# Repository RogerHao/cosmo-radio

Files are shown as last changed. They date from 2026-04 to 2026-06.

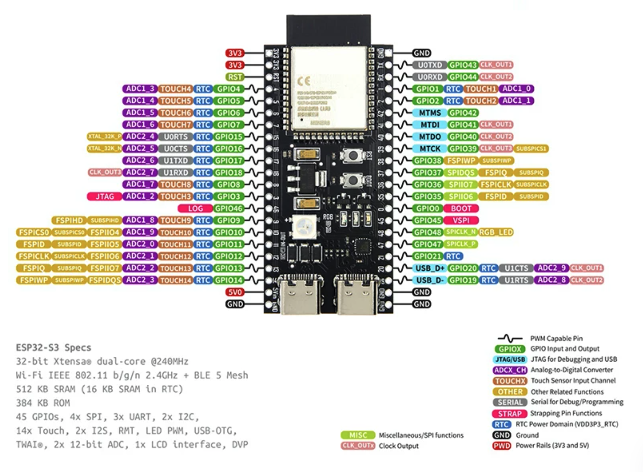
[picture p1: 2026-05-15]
docs/assets/ESP32-S3-DevKitC-N16R8.png

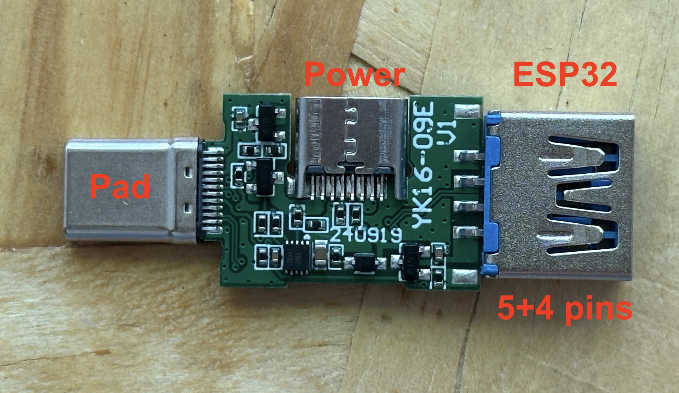
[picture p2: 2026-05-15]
docs/assets/otg-adapter-yk16-09e-photo.jpg

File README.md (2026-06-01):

# CosmoRadio

可穿梭于平行宇宙的 Radio 接收器

## 项目简介

桌面交互设备，安卓平板 + 3D 打印外壳 + ESP32 USB HID 控制器。造型参考 iMac G3 斜面站立式设计，用户通过旋钮调频、NFC 刷卡切换内容，仿佛在平行宇宙间搜索信号。

**当前版本：V4**（2026.04 — 2026.05）— 技术方案验证 + 单套原型制作

> 2026-04-29 与噗噗噗公司确认重启协议：第四期缩小为技术方案验证和单套原型制作，合同价 ¥5,000，目标 2026-05-20 左右交付。原 4 套整机 + 8 套电子套件交付范围已取消。

## 产品形态

- **外观风格**: iMac G3 斜面站立式，模块化三件式（主体 + 顶部 + 背板）
- **显示设计**: 三圆形遮罩（矩形屏幕通过开孔分割为三个圆形显示区）
- **输入方式**: 2 × EC11 旋钮 + Kailh 机械轴按钮 (6.25U 卫星轴) + NFC 刷卡
- **状态指示**: WS2812 RGB LED

## 硬件组成（V4）

| 组件 | 规格 | 用途 |
|---|---|---|
| 安卓平板 | 客户自购 (Samsung Galaxy Tab A9 8.7") | 主机，运行 Web 应用 |
| ESP32-S3 DevKitC N16R8 | 36+ GPIO / USB OTG / 16MB Flash / 8MB PSRAM | HID 控制器 |
| 定制 PCB 载板 | **100×100mm 双面** (JLCPCB 免费打样)，**两条 1×22 单排母** + 5 路 XH2.54 + 4× 10kΩ/10nF 去抖 | 消灭飞线，XH2.54 即插即用 |
| EC11 旋钮 × 2 | 15mm 半轴柄旋转编码器 | 频率调节 / 模式切换 |
| Kailh BOX 轴 + 6.25U 卫星轴 | 机械键盘蝴蝶结构，3.6mm 行程 | Action Button |
| RC522 mini NFC 模块 × 1 | 13.56MHz SPI，读 NTAG215 NDEF | NFC 刷卡交互（最终 1 个，2026-05-06 确认） |
| **OTG dongle (YK16-09E V1) 内置子板** | 拆 USB-A 母座，4 飞线接 J5 → DevKitC 排针 GPIO19/20 + 5V/GND | 平板 Data Host + Power Sink 同时工作 |
| 板载 RGB LED | DevKitC GPIO48 WS2812B | 状态指示（不外接 LED）|

## 连接方案

| 方案 | 固件位置 | 状态 |
|---|---|---|
| USB HID | 项目根目录 | **当前使用** — TinyUSB，即插即用 |
| BLE HID | (已删除，见 git 历史) | V1-V2 遗留，已停用 |

## 交互设计

输入设备通过 ESP32 USB HID 协议作为标准键盘连接到安卓平板，事件以模拟按键传递：

| 输入 | 映射 | 功能 |
|---|---|---|
| 顶部 Action 按钮 | Enter 键 | 确认选择 |
| EC11 左 旋转 | 上/下方向键 | 调节频率 |
| EC11 左 按下 | F1（占位，平板可重映射） | 扩展功能位 |
| EC11 右 旋转 | 左/右方向键 | 切换模式 |
| EC11 右 按下 | F2（占位，平板可重映射） | 扩展功能位 |
| NFC 卡（写了 NDEF Text） | `<payload>\n` | **主路径**：固件读卡上写入的字符串，原样键入 + Enter（无前缀） |
| NFC 卡（空白 / 非 NDEF） | `NFC:<UID>\n` | 兜底：识别失败时键入 UID 方便诊断 |

### NFC 协议设计

为了让产品身份与 NFC 卡 UID 解耦（UID 不可控且需要逐张录入），固件读取卡上的 NDEF Text Record 内容作为产品 ID。流程：

1. 出厂前用任一手机 NFC 工具 app 把每张卡写入特定字符串（如 `R01`、`track-42`）
2. 用户放卡 → 固件读 NDEF → HID 键入 `R01\n`
3. 平板侧 Android 应用结合页面状态/输入长度判断当前是 NFC payload 还是普通 HID 键入；`NFC:` 前缀仅出现在 UID 兜底路径，方便区分

### LED 状态指示（DevKitC 板载 GPIO48 RGB LED）

| 事件 | LED 颜色 |
|---|---|
| 按钮按下 | 红色 |
| 按钮释放 | 熄灭 |
| NFC 识别中（键入期间） | 蓝色 |
| 启动完成 | 绿色闪烁 |

## 项目结构

```
cosmo-radio/                            # 项目根 = ESP-IDF USB HID 固件
├── main/
│   ├── tusb_hid_example_main.c         # 入口：USB HID + ASCII→HID 编码
│   ├── input_handler.c/h               # GPIO 中断 + 物理电平复核输入（按钮 + 双 EC11）
│   ├── nfc_handler.c/h                 # RC522 SPI 扫描 + NDEF Text 解析
│   └── led_indicator.c/h               # 板载 WS2812 RGB（GPIO48）
├── sdkconfig.defaults
├── CMakeLists.txt
├── pcb/                                # 嘉立创EDA r1.0 验证版工程 + 制造文件
├── models/                             # 3D 模型（v4 = 最终交付集）
├── docs/
│   ├── assets/                         # 元器件引脚图、原型照片
│   ├── firmware/                       # 固件实现文档
│   ├── hardware/                       # 硬件模块设计方案（NFC、USB...）
│   ├── legacy/                         # 弃用内容
│   └── project/ → codex                # BOM、PCB Spec、项目主文档
└── test/
    └── hid-test.html
```

## 相关项目

- [cosmo-pager-web-nextjs-vercel](https://github.com/RogerHao/cosmo-pager-web-nextjs-vercel) — Web 应用前端（客户软件团队开发）

## 版本历史

| 版本 | 时间 | 主控 | 连接 | 主要变化 |
|---|---|---|---|---|
| V1 | 2025 Q3-Q4 | Adafruit HUZZAH32 | — | 硬件预研 |
| V2 | 2025.12-2026.01 | XIAO ESP32S3 | BLE HID | 首批组装，硅谷交付 |
| V3 | 2026.01-2026.02 | ESP32-S3 SuperMini | USB HID | BLE→USB 切换，12 套交付 |
| **V4** | **2026.04-2026.05** | **ESP32-S3 DevKitC N16R8** | **USB HID** | **模块化 PCB + NFC + 机械按钮，单套原型验证** |

## V4 进度

**2026-06-01 第四期结项 ✅**——技术验证 2026-05-22 完成，2026-05-31 客户收到成品交付，2026-06-01 开票收款 ¥5,000（累计 ¥31,000 全部结清）。

**2026-05-22 V4 技术验证交付完成 ✅**——PCB r1.0 实焊 + 双板并排功能验证通过，单套原型装配完成。详见 [V4 资料包](project/v4/shared/先读说明.md)。

已交付：
- [x] 2026-04-29 与噗噗噗公司重启 V4：技术方案验证 + 单套原型，合同价 ¥5,000
- [x] USB-C 充电方案：被动 SS34 注入实测失败 → 内置一分二 OTG 线材子板（YK16-09E V1）验证通过
- [x] NFC 数量确认：1 个 RC522 mini（2026-05-06）
- [x] 万能板飞线原型焊接 + GPIO 验证（2026-05-06，[图片](docs/assets/v4-handmade-prototype-2026-05-06.jpg)）
- [x] 固件 V4 GPIO 迁移（SuperMini → DevKitC N16R8）+ HID 多键并发
- [x] NFC 驱动开发（RC522 SPI + NDEF Text Record 解析）
- [x] 旋钮 + NFC HID 协议定稿（NDEF payload 原样键入，无前缀 + `NFC:<UID>` 兜底）
- [x] 端到端验证：iPhone 写卡 → ESP32 读 NDEF → HID 键入（2026-05-15 实卡验证）
- [x] **PCB r1.0 载板**：嘉立创EDA手绘 → 打样 → 实焊 → 功能验证（源文件 `pcb/cosmoradio-v4-jlceda/`）
- [x] 单套整机原型装配（[Fusion 装配 `cosmo-radio-v4-prototype`，模型 `models/v4/`]）
- [x] Action Button 最终手感、整机热稳定 + 2h 充电链路、NFC 穿透壁厚读距回归（2026-05-24 结项确认）
- [x] 固件安全回归：按钮释放物理电平复核、HID key-up 重试、NFC 启动后台重试（2026-05-28 PCB 实机烧录验证）

结项归档待办：
- [ ] PCB 制造文件从嘉立创EDA导出归档（清单见 [pcb/README.md](pcb/README.md)）
- [ ] r1.1 优化（J4 改对称去 walkaround、NFC 5MHz）— 见验证报告 §6

## 构建与烧录

```bash
get_idf                                    # 激活 ESP-IDF 环境
idf.py set-target esp32s3                  # 设置目标芯片（首次）
idf.py build                               # 构建
idf.py -p /dev/cu.usbmodem* flash monitor  # 烧录并监控
```

> ⚠️ 烧录必须走 DevKitC 的 **UART USB-C** 口（本板 UART 桥是 WCH CH343），别插 native/OTG 口——两个口在 macOS 下都枚举成 `usbmodem`，靠 USB VID 区分（`0x1A86`=UART 桥可烧 / `0x303A`=OTG 口烧不了）。详见 [CLAUDE.md "烧录端口"](CLAUDE.md)。

## GPIO 引脚分配

完整 GPIO → net → 连接器 映射、PCB 物理位置、PCB r1.0 EC11-R 接线 walkaround 全部见 [CLAUDE.md "GPIO Pin Assignments"](CLAUDE.md#gpio-pin-assignments-v4-pcb-r10--esp32-s3-devkitc-n16r8)。固件里 `main/input_handler.c` 和 `main/nfc_handler.c` 的 `#define` 是各自的 GPIO 角色权威源。

> 简易记忆：左旋钮 → J3，右旋钮 → J4 (引脚顺序跟 J3 镜像)，BTN → J1，NFC → J2，USB → J5。V3 引脚分配（SuperMini）见 git 历史。

## 文档索引

**交付（客户）**
- [V4 资料包先读](project/v4/shared/先读说明.md) ⭐ 交付核心
- [产品功能与当前边界](project/v4/shared/产品功能与当前边界.md)
- [平板对接协议](project/v4/shared/平板对接协议.md)
- [硬件参考资料](project/v4/shared/硬件参考资料.md)
- [复现与维护指南](project/v4/shared/复现与维护指南.md)
- [物料清单与采购参考](project/v4/shared/物料清单与采购参考.md)

**硬件方案**
- [USB 接口方案](docs/hardware/usb.md)
- [NFC 模块方案](docs/hardware/nfc.md)
- [OTG 一分二适配器（内置子板）](docs/hardware/otg-adapter.md)

**内部**
- [V4 内部成本备忘录](project/v4/internal/CosmoRadio-V4-内部成本备忘录.md) — 内部，不交付
- [V4 项目内部主文档](project/v4/internal/cosmoradio-yangweile-customized-hardware.md) — 内部，不交付
- [V4 待办事项](TODO.md)

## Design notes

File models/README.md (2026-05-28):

# CosmoRadio 3D 模型

外壳与结构件的 3D 打印模型索引。`v4/` 是 V4 技术验证交付模型集，对应单套原型（iMac G3 斜面站立式，三圆形 IOI 遮罩 + 顶部 Action Button + NFC）。Fusion 360 云端装配工程名：`cosmo-radio-v4-prototype`。

> 模型二进制文件（STL / 3MF / STEP）被 `.gitignore` 排除，不进 git。交接/交付时，实际模型文件走飞书或独立压缩包；不能靠 clone 仓库获得。

详细打印文件和截图见：[V4 交付包 / 3D打印文件](../project/v4/shared/3D打印文件/)。

## v4/ — V4 模型集

### STL 零件

| 文件 | 零件 | 说明 |
|---|---|---|
| `外壳主体.stl` | 外壳主体 | 三圆遮罩开孔主体 |
| `外壳背板.stl` | 外壳背板 | 主背板 |
| `充电背板.stl` | 充电口背件 | OTG / 充电线材出入口结构 |
| `按钮安装外壳.stl` | Action Button 安装座 | Kailh BOX 轴 + 6.25U 卫星轴安装结构 |
| `圆润按钮.stl` | 圆润按钮键帽 | 默认按钮形态 |
| `标准按钮.stl` | 标准按钮键帽 | 备选按钮形态 |
| `NFC安装外壳.stl` | NFC 安装外壳 | RC522 mini 模块安装壳 |
| `NFC固定支架.stl` | NFC 固定支架 | NFC 模块压紧 / 固定件 |
| `平板固定支架.stl` | 平板固定支架 | 已进入整套打印工程 Plate 4 |
| `底部圆脚.stl` | 底部圆脚 | 单套 4 个 |
| `旋钮.stl` | EC11 旋钮帽 | 单套 2 个 |

### 3MF 工程

| 文件 | 说明 |
|---|---|
| `CosmoRadio-V4-整套打印.3mf` | 正式整套打印工程，含 4 个 plate：外壳主体 / 配件 / 外壳背板 / 充电背板及平板固定支架 |
| `NFC固定支架.3mf` | 历史整套工程副本，交付时以 `CosmoRadio-V4-整套打印.3mf` 为准 |
| `外壳主体.3mf` | 外壳主体单件工程 |
| `外壳背板.3mf` | 外壳背板单件工程 |
| `充电模块.3mf` | 充电口背件单件工程 |
| `按钮安装外壳.3mf` | Action Button 安装座单件工程 |
| `标准按钮.3mf` | 标准按钮键帽单件工程（备选按钮） |
| `NFC安装外壳.3mf` | NFC 安装外壳单件工程 |
| `NFC测试标签.3mf` | NFC 标签 / 测试件，不属于整机必需外壳件 |

### 打印信息

| 文件 | 说明 |
|---|---|
| `打印信息/整套打印-plate截图.png` | 当前整套工程 plate 排布截图 |
| `打印信息/打印截图.png` | 旧版 plate 排布截图 |
| `打印信息/打印消耗.png` | Bambu Studio 预估耗材和时间截图 |

当前整套工程预估：4 个 plate，PLA 397.70g，总打印时间 12h57m。完整参数见 V4 3D 打印说明。

## 历史版本

| 目录 | 版本 | 主控 | 形态 |
|---|---|---|---|
| `v1/` | V1（2025 Q3-Q4） | Adafruit HUZZAH32 | 硬件预研，多版前后壳迭代 |
| `v2/` | V2（2025.12-2026.01） | XIAO ESP32S3 | BLE HID，硅谷首批组装 |
| `CosmoRadio-V3-模型及拓竹P2S打印工程切片文件/` | V3（2026.01-2026.02） | ESP32-S3 SuperMini | USB HID，12 套交付（含 STEP 源 + P2S 切片） |

V3 目录含完整 `.step` 参数化源文件；v1/v2/v4 主要为 STL/3MF。

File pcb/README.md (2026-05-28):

# CosmoRadio V4 PCB

> **状态（2026-05-22）**：**r1.0 已打样 + 实焊 + 双板并排固件验证通过**。这是 V4 技术验证交付的 PCB 终版。
>
> **设计源文件唯一权威**：[`cosmoradio-v4-jlceda/`](cosmoradio-v4-jlceda/)（嘉立创EDA专业版手绘）。
> 仓库历史里出现过的 KiCad `cosmoradio-v4-carrier/`（Plan v2，circuit-synth + pcbnew 自动布线备选）**从未打样、未使用，已删除**——如需追溯见 git 历史。

CosmoRadio V4 的 PCB 是一块 **ESP32-S3 DevKitC N16R8 载板（carrier board）**，用于技术方案验证和单套原型制作。目标不是量产最优，而是：可快速打样、可手工装配、可稳定验证 USB HID + 外部充电 + 旋钮 + 按钮 + NFC、出问题易测量返修。

---

## 设计源文件与制造产物

| 文件 | 内容 | 状态 |
|---|---|---|
| [`cosmoradio-v4-jlceda/cosmoradio-v4-r1.0.epro2`](cosmoradio-v4-jlceda/) | 嘉立创EDA专业版可移植工程（原理图 + PCB） | ✅ 验证版唯一真源 |
| [`cosmoradio-v4-jlceda/cosmoradio-v4-r1.0-schematic.png`](cosmoradio-v4-jlceda/) | 原理图渲染（从工程导出） | ✅ |
| `cosmoradio-v4-jlceda/manufacturing/` | Gerber / 钻孔 / 坐标 / BOM / 原理图 PDF / STEP / DXF | ✅ 已导出归档 |

### 从嘉立创EDA专业版导出制造文件（清单）

> 制造文件无法从 `.epro2` 的 JSON 直接生成，必须在嘉立创EDA专业版 GUI 里导出（参 [官方文档](https://prodocs.lceda.cn/cn/pcb/export-pcb-fabrication-file-gerber/)）。
> 当前 r1.0 导出文件已归档到 `manufacturing/`。如需重新导出，用 v3.2.135+ 打开 `cosmoradio-v4-r1.0.epro2` 后，逐项导出到 `manufacturing/`：

| # | 产物 | 菜单路径 | 备注 |
|---|---|---|---|
| 1 | **Gerber + 钻孔** | `文件 → 导出 → PCB制板文件（Gerber）` | 输出一个 zip（.GTL/.GBL/.DRL…），即 JLCPCB 上板包 |
| 2 | **坐标文件**（贴片） | `导出 → 坐标文件` | SMT 用；本板被动件少，仅 8× 0805 |
| 3 | **BOM** | `导出 → BOM` | 物料清单 |
| 4 | **原理图 PDF** | `原理图编辑器 → 导出 → PDF/图片` | |
| 5 | **PCB PDF / 图片** | `PCB编辑器 → 导出 → PDF/图片` | 含丝印/阻焊层，便于核对 |
| 6 | **3D STEP** | `PCB编辑器 → 导出 → 3D文件` | 给结构设计对位用 |
| 7 | **板框 DXF** | `文件 → 导出 → DXF` | 给结构设计对位用 |

> 上板前用嘉立创 DFM 工具或 Gerber 查看器复核一遍再下单。导出完成后把文件放进 `manufacturing/`，我来核对归档。

---

## 当前范围

| 项目 | 结论 |
|---|---|
| 合作状态 | 2026-04-29 与 Arthur 重启 V4 |
| 当前交付 | 技术方案验证 + 单套原型制作 |
| 合同价 | ¥5,000 |
| 核心风险 | PCB 设计与验证（已通过） |
| 非当前目标 | 原 4 套整机 + 8 套电子件批量交付 |

## 验证里程碑

**2026-05-07 整体方案验证完成 ✅**——电气、固件、NFC 协议在万能板飞线版上端到端跑通，所有方案级未知收敛。

| 项目 | 状态 |
|---|---|
| NFC 数量 | ✅ 1 个 RC522 mini |
| 一分二 OTG + 充电线材 | ✅ 多型号实测，选定 YK16-09E V1 作内置子板基准 |
| 手工万能板原型 | ✅ 已焊（[图片](../docs/assets/v4-handmade-prototype-2026-05-06.jpg)） |
| GPIO 分配 | ✅ V4 终版定稿，权威表见 [CLAUDE.md](../CLAUDE.md) |
| RC522 NFC 驱动 | ✅ 1MHz SPI + NDEF Text Record 解析 |
| HID 协议 | ✅ NDEF payload 主路径 + `NFC:<UID>` 兜底 |
| 端到端验证 | ✅ iPhone 写卡 → ESP32 读 NDEF → HID 键入 |

**2026-05-22 PCB r1.0 实焊验证完成 ✅**

- ✅ 嘉立创EDA手绘原理图 → 打样 → 焊接 → DevKitC 插入 → JST 端子线压接
- ✅ 双 EC11 + Action Button + NFC + USB HID 全链路验证通过（两台板子并排测）
- ⚠ **已知 r1.0 issue**：J4 (EC11-R) 引脚顺序画成跟 J3 镜像，物理 EC11 端子线序错位。**固件已 walkaround**（`main/input_handler.c` 重指派 `GPIO_ENC2_A/B/SW` + swap A↔B，见 [CLAUDE.md "PCB r1.0 EC11-R 接线 walkaround"](../CLAUDE.md)），硬件无需返工。
- ⚠ 原理图里 H-L pin1 / H-R pin1·pin2 的 GND/+5V 标签标错；r1.0 因走线没真连而幸免，r1.1 应改正。
- ⏳ 待新 Tab A9 到货后补整机长时间热稳定 + 2h 充电链路回归（当前在安卓手机上验证）。

## 板子定位

ESP32-S3 DevKitC 通过 2.54mm 排母插在载板上（不焊死，易更换），载板只负责固定主控与外设线束、消灭 V3 的飞线、把旋钮/按钮/NFC/USB 标准化、提供必要的上拉/RC 去抖。

```mermaid
flowchart LR
    tablet[Android 平板 Tab A9] <-- USB HID --> pcb[CosmoRadio V4 载板 r1.0]
    charger[USB-C 充电器] --> dongle[内置 OTG dongle 子板]
    dongle --> pcb
    pcb --> devkit[ESP32-S3 DevKitC N16R8]
    pcb --> enc1[EC11 左旋钮 J3]
    pcb --> enc2[EC11 右旋钮 J4]
    pcb --> btn[Action Button J1]
    pcb --> nfc[RC522 NFC J2]
```

## 接口定义（r1.0）

权威 GPIO → net 映射见 [CLAUDE.md "GPIO Pin Assignments"](../CLAUDE.md)。下表为 PCB 视角的连接器物理接线：

| Ref | 接口 | 类型 | 连接对象 | 信号（按 pin 顺序）|
|-----|---|---|---|---|
| H-L | DevKitC 左列 socket | 1×22P 排母 2.54mm | DevKitC 左侧排针 | 含 GPIO19/20 + EC11-L + BTN |
| H-R | DevKitC 右列 socket | 1×22P 排母 2.54mm | DevKitC 右侧排针 | 含 EC11-R + NFC SPI |
| J1 | BTN | XH2.54 2P | Kailh BOX 按钮 | pin1=SIG, pin2=GND |
| J2 | NFC | XH2.54 8P | RC522 mini | CS, SCK, MOSI, MISO, IRQ, GND, RST, VCC |
| J3 | EC11-L（用户左旋钮） | XH2.54 5P | 左旋钮 | pin1-5 = A, GND, B, GND, SW |
| J4 | EC11-R（用户右旋钮） | XH2.54 5P | 右旋钮 | pin1-5 = SW, GND, B, GND, A ⚠ 跟 J3 镜像，r1.1 改对称 |
| J5 | OTG USB 数据 | XH2.54 4P | OTG dongle 拆 USB-A 后 4 飞线 | pin1-4 = VBUS, D-, D+, GND |

> H-L 中心距 H-R = **22.86mm**（= 9 × 2.54mm pitch），breadboard 兼容，以飞线万能板实测为准。

## 原理图元件清单（r1.0，14 元件 + 4 螺柱位）

| Ref | 元件 | 封装 | 说明 |
|-----|---|---|---|
| H-L, H-R | 1×22P 排母座 (×2) | 2.54mm THT | DevKitC 插入 |
| J1 | XH2.54 2P 立式直针座 | THT | Action Button |
| J2 | XH2.54 8P 立式直针座 | THT | RC522 NFC |
| J3, J4 | XH2.54 5P 立式直针座 (×2) | THT | EC11 旋钮 |
| J5 | XH2.54 4P 立式直针座 | THT | OTG dongle USB 数据 |
| R1-R4 | 10kΩ 上拉（EC11 A/B） | 0805 | LCSC C17414 |
| C1-C4 | 10nF 对 GND（EC11 A/B） | 0805 X7R 50V | RC 去抖，τ=100µs |
| U1-U4 | M2.5 固定螺柱位 | 通孔 | 四角 |

**相对旧 spec 取消的元件**：USB-C 母座（充电改走 OTG dongle 内部）、USB-C CC 5.1k Rd ×4、SS34 防倒灌、外接 WS2812B + 330Ω（LED 改用 DevKitC GPIO48 板载 RGB）。

## PCB 物理约束

| 项目 | 值 |
|---|---|
| 尺寸 | **100mm × 100mm**（JLC 免费打样上限）|
| 层数 / 板厚 / 铜厚 | 2 层 / 1.6mm / 1oz |
| 表面 / 阻焊 / 丝印 | HASL 无铅 / 黑油 / 白字 |
| 安装孔 | 4 × M2.5（四角，孔径 2.7mm）|
| 制造 | JLCPCB 5 片打样 |
| 装配 | 不上 SMT；纯打板，8× 0805 + 6 个连接器手焊 ~15min |

连接器物理位置（用户俯视）：**顶部** J5；**左侧** J1（靠前）/ J3（中段）；**右侧** J4（中段）/ J2（底部）。顶丝印有 **"OTG USB-C: DO NOT PLUG"** 警示——GPIO19/20 同时连到 J5 和 DevKitC native USB-C 焊盘，运行时插板载 OTG USB-C 会跟 dongle 注入冲突；烧录走 DevKitC **UART** USB-C。

---

## 关键设计判断（决策记录）

### 混合焊接：低风险小器件贴片，高机械应力器件直插

| 类型 | 方案 | 理由 |
|---|---|---|
| 电阻 / 电容 | 0805 SMD | 适合加热台，布线短，易返修 |
| JST-XH 连接器 | 直插件 | 插拔受力大，原型更可靠 |
| DevKitC 排母 | 直插件 | 承重和插拔受力，不适合贴片 |

比全直插件整洁，比全贴片更适合单套原型。

### NFC 连接器按 8P 处理

以 RC522 mini 实物丝印为准：`CS, SCK, MOSI, MISO, IRQ, GND, RST, 3V3`（8P）。IRQ 第一版接出但固件未用，避免后续想做中断驱动时改板。

### EC11 A/B 加 RC 去抖

A/B 信号各加 10kΩ 上拉 + 10nF 对地（τ=100µs），既增强边沿陡度又抑制机械抖动——解决飞线版上"一格不准、内部上拉不够脆"的问题。SW 仅靠内部上拉。

### USB / 充电：选定"拆解成品 OTG dongle 内置"而非自研 PD 子板

核心约束：Tab A9 必须同时是 **Data Host**（host ESP32）+ **Power Sink**（被外部充电）——这不是 USB-C 默认角色组合，需要角色拆分。

- ✅ **成品一分二 OTG + 充电线材**已实测让 Tab A9/Android 同时 HID 输入 + 充电 → 证明设备支持该状态。V4 选定拆解 YK16-09E V1、取内部 PCB 内置（J5 4 飞线）。
- ❌ **被动 SS34 + 6P 转接板注入 VBUS**（2026-04-30 实测失败）：即使配 5.1k Rd，也只能让平板识别 OTG 设备，无法完成 Type-C/PD 角色协商进入充电态。已降级为失败路径记录，不再作为主线。
- ⏸ **自研 LDR6028/LDR6023C PD charge-through 子板**：技术可行但价值在形态可控而非降成本（不比 ¥20 级成品线材便宜，且有协议调试风险）。后续方案，不塞进第一版。
- ❌ **BLE HID + USB-C 只充电**：BLE HID 实测不稳定且违反"必须有线 HID"硬约束，排除。

> 深度调研见 [`research/Tab_A9_OTG_Charging_Feasibility_Report.md`](research/Tab_A9_OTG_Charging_Feasibility_Report.md)（2026-04-30 Manus 调研，针对半主动方案偏负面；后续实测一分二线材修正了"设备能力"判断，但确认被动复刻不够）。

---

## r1.1 路线（未启动，post-delivery）

r1.0 已满足 V4 技术验证交付。若后续迭代，r1.1 应：

1. 把 J4 (EC11-R) 引脚顺序改回跟 J3 对称的 `[A, GND, B, GND, SW]`，去掉固件 `input_handler.c` 里的 EC11-R walkaround。
2. 修正原理图里 H-L pin1 / H-R pin1·pin2 的 GND/+5V 误标。
3. 尝试把 NFC SPI 时钟从 1MHz 拉回 5MHz（铜箔走线 + 去耦后应可稳定，飞线版受 RF 噪声限制）。
4. 整机长时间热稳定 + 2h 充电链路回归（需新 Tab A9）。

## 目录

```
pcb/
├── README.md                          # 本文件
├── cosmoradio-v4-jlceda/              # ✅ r1.0 验证版唯一真源
│   ├── cosmoradio-v4-r1.0.epro2       #   嘉立创EDA可移植工程
│   ├── cosmoradio-v4-r1.0-schematic.png
│   └── manufacturing/                 #   Gerber/BOM/坐标/PDF/STEP/DXF
├── asset/                             # 飞线测试版照片 + DevKitC 引脚图
└── research/                          # Tab A9 OTG 充电可行性调研
```

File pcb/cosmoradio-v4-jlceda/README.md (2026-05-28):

# CosmoRadio V4 载板 — r1.0 验证版（嘉立创EDA专业版）

这是 **V4 实焊验证通过的 PCB 唯一权威设计源**。

| 文件 | 内容 |
|---|---|
| `cosmoradio-v4-r1.0.epro2` | 嘉立创EDA专业版可移植工程（zip：原理图 + PCB + 元件库）。用 v3.2.135+ 打开。 |
| `cosmoradio-v4-r1.0-schematic.png` | 原理图渲染（从工程导出，1920×1360） |
| `manufacturing/` | Gerber / 钻孔 / 坐标 / BOM / 原理图 PDF / STEP / DXF |

制造文件已归档到 `manufacturing/`。重新导出步骤（菜单路径、DFM 复核）见上层 [`../README.md`](../README.md) "从嘉立创EDA专业版导出制造文件"。

> r1.0 已知 issue（J4 镜像、H-L/H-R 标签误标）与 r1.1 路线见 `../README.md`。固件已 walkaround，硬件无需返工。

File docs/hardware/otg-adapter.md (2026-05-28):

# OTG 一分二适配器 — 集成分析

> 标记号：YK16-09E V1（板上丝印，日期码 240919）
> 用途：让 Tab A9 同时处于 **Data Host**（接收 ESP32 的 USB HID）+ **Power Sink**（被外部充电器充电）
> 当前状态：作为内置子板已采购、已实测 OTG + 充电同时工作；**仅剩 dongle USB-A ↔ ESP32 之间的一根 USB 3.0 线**外露在主板侧

参考图：[otg-adapter-yk16-09e-photo.jpg](../assets/otg-adapter-yk16-09e-photo.jpg)

## 1. 这块小板内部到底在做什么

从照片可以看到三个端口和板间一颗小型 IC：

| 端口 | 类型 | 角色 | 走向 |
|---|---|---|---|
| 左（"Pad"） | **Type-C 公头**（焊接式 plug，已带短缆） | DFP 视角的 Power Sink，但宣告自己是 USB Host (DFP/Host) 的 Data Role | 插入 Tab A9 |
| 中（"Power"） | **Type-C 母座** | UFP/Sink → 上行接外部充电器（Source） | 充电器 |
| 右（"ESP32"） | **USB 3.0 Type-A 母座**（9 pin） | 标准 USB Host 提供给下游设备 | 经一根 USB 3.0 线连到 ESP32-S3 DevKitC 自带 USB-C |

中间那颗带丝印的 IC 是关键，它干三件事：

1. **CC 线协商**：在朝向平板的 Type-C plug 上呈现 Rp（pull-up），并通过 PD BMC（或固定 CC pattern）告诉平板"我是 Host + Sink"。这一步用普通 5.1k 上拉/下拉电阻**做不到**——`pcb/README.md` 里 6P 转接板 + SS34 的失败就是这个原因。
2. **Power Role / Data Role 编排**：让平板内部把电源开关切到 Sink 路径（充电器电直接进电池），同时数据通路保持在 Host 模式（向下游提供 USB Host）。
3. **VBUS 路由 + 反灌保护**：把充电器的 5V 经高边 MOSFET 转接给平板 VBUS，同时阻止平板侧 VBUS 倒灌进充电器或下游设备。

这颗 IC 大概率是 LDR6028/LDR6023C 一族（5V OTG + 充电控制器）或 IP2721 类，**没有从板上拆下来在显微镜下看丝印之前不能 100% 确认**。

## 2. ESP32-S3 实际只用 9 pin 中的 4 pin

| 引脚 | 用途 | ESP32 是否用 |
|---|---|---|
| VBUS | 5V 电源 | ✅ 走 DevKitC 的 5V 输入 |
| GND  | 地 | ✅ |
| D+ / D- | USB 2.0 高速差分对（480 Mbps） | ✅ |
| StdA_SSRX± / StdA_SSTX± / GND_DRAIN | USB 3.0 SuperSpeed 通道（5 GT/s+） | ❌ 全部空跑 |

**结论**：USB-A 一侧 9 pin 里有 5 pin 完全是浪费。把这条 USB 3.0 线消灭只需要把 4 根线（VBUS、GND、D+、D-）从 dongle 直接接到主 PCB 即可。

## 3. 三种集成路径，按风险从低到高排

### 方案 1（推荐 V4 采用）：拆 USB-A 母座，4 根短线直连主 PCB

**做法**：
1. 把 dongle 上的 USB 3.0 Type-A 母座从板上拆下来（USB-A 受电力 + 信号都在板边焊盘，9 pin 加 2-4 个机械固定脚，热风枪 30s 可下件）。
2. 露出 4 个有用焊盘：VBUS、GND、D+、D-。
3. 焊 4 根 AWG28-AWG30 信号线到主 PCB 上一个新增的 4P XH2.54 连接器（或直接 4 个焊盘 + 应力释放）。
4. 主 PCB 这一侧用一根短跳线接到 ESP32-S3 DevKitC 的 USB-C 座（保持 DevKitC 不变）；或者后续 PCB rev 把 ESP32-S3 的 GPIO19/20/5V/GND 直接走到这个 4P 连接器，整条 USB-C 线也省掉。

**优点**：
- 不动 dongle 上的 PD/CC 控制 IC，电气行为 0 变化。
- 工艺非常确定：拆一个 USB-A 座 + 焊 4 根线，半小时收工。
- USB 2.0 HS 480 Mbps 在 <10 cm 短线上完全不需要阻抗匹配/length matching。
- 任何一头坏了都好换。

**缺点**：
- dongle 仍是一块独立小板，机械固定方案要做（双面胶 / 螺丝柱 / 卡扣）。
- BOM 里仍有"成品 dongle 整片"这一项，不是真正"自研一片主 PCB 含 OTG"。

**成本**：dongle ¥15-25 + 4 根线 ¥0 + 1 个 4P 连接器 ¥0.5。比当前少一根 USB 3.0 线（~¥10）。

**适合 V4** —— 04/29 重启的 V4 范围是"技术验证 + 单套原型"，2026-05-20 前要交付。这条路径**风险几乎为零**，今天就能动手。

### 方案 2：dongle USB-A 焊盘改 2.54 排针，主 PCB 出 4P 排母

**做法**：把 USB-A 拆掉后不焊飞线，而是焊一个 4P 2.54 直插排针；主 PCB 对应位置放排母。

**优点**：可拆卸，调试期间方便单独验证 dongle 或主 PCB。

**缺点**：增加了机械应力点，长期连接可靠性略差，不如直接焊死。

**适合**：调试阶段做，到最终组装再焊死，等于"1 + 2 混合"。

### 方案 3（推迟到 V5）：把 dongle 内部电路完整复刻到主 PCB

**做法**：
1. 拆 dongle，显微镜读丝印识别 CC 控制 IC（关键步骤——丝印不清就死路一条，需要好相机 + 侧光）。
2. 找到 datasheet 后，把 IC、外围被动件、ESD/TVS 阵列、VBUS 路径 MOSFET 全部画进 KiCad 原理图。
3. 主 PCB 上加 1 个 Type-C 充电母座 + 1 根 Type-C 公头 pigtail（去往平板）。
4. 重新过 JLCPCB（5 天打板 + 3 天到货），做 PD/CC 行为回归测试。

**优点**：彻底单板化、形态最干净、可量产。

**缺点 / 风险**：
- IC 识别失败 → 整条路径作废（实物焊在板上的 SOT-23-6/QFN 丝印往往只有 2-3 字符代号，要查代号表，不一定能查到）。
- 即使识别出 IC，PD/CC 行为复刻不一定 1:1 一致；Tab A9 这类设备对 CC 时序敏感，可能要协议分析仪才能调通。
- 时间预算 ≥ 一个 PCB rev cycle，约 10-15 天，**吃光 V4 剩余周期**。

**结论**：**不要塞进 V4。** 这是 V5（如果客户后续要小批量量产）才动的活。文档里把这条路径标为"未来工作"即可。

## 4. 给 V4 的具体决定

| 项 | 决定 |
|----|---|
| OTG dongle | **保留为内置子板**（YK16-09E V1） |
| dongle ↔ ESP32 之间的 USB 3.0 线 | **消灭**：拆 USB-A 母座 → 4 根飞线 → 主 PCB 4P XH2.54 连接器 |
| 主 PCB 上是否新增 PD/CC 控制 IC | **不新增** |
| 主 PCB 上是否新增 Type-C 母座（充电输入） | **不新增**（充电仍走 dongle 上自带的 Type-C 母座） |
| 朝向平板的 Type-C 公头线 | **保留 dongle 自带的**（它就是焊在 dongle 板上的 plug + 短缆） |
| 后续工作（V5+） | 显微镜读 IC 丝印 → 复刻入主 PCB |

## 5. 在动手之前要做的小件事（10 分钟）

1. **拍一张 dongle 中央 IC 的高分辨率照片**（手机 macro 或 USB 显微镜，侧光读丝印）。即使本期不复刻，IC 型号也是 V5 文档的金字塔基。把照片存成 `docs/assets/otg-adapter-yk16-09e-ic-marking.jpg`。
2. **量一下 dongle PCB 物理尺寸**（含 Type-C plug 短缆出板方向 + 长度 + 三个端口的开口位置），决定外壳里给它留哪一块平面 + 螺丝柱。
3. **确认 USB-A 母座下件后的 4 个焊盘极性**（VBUS、D-、D+、GND，从左到右是 USB-A 标准定义，但实物板可能镜像）。可以用万用表通断从 USB-A 金属壳和 4 个 pin 之间反查。

## 6. 主 PCB 改动清单

如果 V4 PCB 还没下单，加这几项；如果已经下单，飞线接也行：

- 新增 1 个 **J5（dongle USB 数据接入）** = 4P XH2.54 立式直插，位于 PCB 边缘靠近 ESP32-S3 DevKitC USB-C 那一侧。
- 信号顺序建议 `VBUS / D- / D+ / GND`（与 USB-A 物理顺序一致，方便排查）。
- VBUS 走线宽度 ≥ 0.6 mm（承载 ≤2 A 充电电流过路）。
- D+ / D- 走差分对，宽度 ~0.2 mm，间距 ~0.13 mm，长度匹配差 < 5 mm（USB 2.0 HS 容差很宽）。
- 在 J5 上的 D+ / D- 各预留一个不焊接的 ESD 二极管位（USBLC6-2 类或 0402 TVS），现版可以 0Ω 跳过。

## 7. 文档前后兼容

- `docs/hardware/usb.md` 中"方案 A / B / C"分析仍保留为历史参考，但其结论已被 dongle 实测 + 本文件覆盖。
- `pcb/README.md` 第 113-115 行的优先级表里，本方案对应 P1（"拆解一分二线材，取内部 PCB，短线/板内固定"），现在升级为 V4 主路径。
- BOM 与成本口径已归入 [物料清单与采购参考](../../project/v4/shared/物料清单与采购参考.md)：最终 OTG dongle 选型为 CKTUTU YK16-09E V1，¥10/个。

## 8. 一句话总结

**能集成，但分两步走。** V4 阶段把 dongle 当成"焊死的内置子板"，仅消灭 USB 3.0 长线（4 根飞线即可，零电气改动）；V5 阶段再考虑识别 dongle 上的 CC 控制 IC、整板复刻。这样 V4 deadline (2026-05-20) 守得住，长期可控性也保住了。

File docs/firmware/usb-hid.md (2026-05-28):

# USB HID 固件实现

> ⚠️ **2026-05-18 状态**：本文件原始内容（V2 XIAO ESP32S3 时代 GPIO 1/D0 描述）已过时，整理为下方简明版。
> 完整 V4 实现细节见 [`/CLAUDE.md`](../../CLAUDE.md) "HID Key Mappings" + "GPIO Pin Assignments"。

## 概述

基于 **TinyUSB** 的 USB HID 键盘实现，运行在 **ESP32-S3 DevKitC N16R8**。把物理输入（双 EC11 旋钮 + Kailh BOX 按钮 + RC522 NFC）转换为键盘事件。USB OTG 通过外置 dongle (YK16-09E V1) 实现"平板 USB Host + 充电"同时工作。

V1/V2 BLE HID 方案已删除（见 git 历史）；V3 SuperMini → V4 DevKitC N16R8 已完成迁移。

## 当前固件入口

| 文件 | 职责 |
|---|---|
| `main/tusb_hid_example_main.c` | TinyUSB 初始化 + ASCII→HID keycode 编码 + 多键并发报告管理（`s_pressed_keys[6]` + `s_hid_mutex`）|
| `main/input_handler.c/h` | GPIO 中断驱动状态机：Action Button + 双 EC11 (A/B/SW)，事件队列分发 |
| `main/nfc_handler.c/h` | RC522 SPI (1MHz, SPI2 via GPIO Matrix) + NDEF Text Record 解析 + 1.5s 同卡去重 |
| `main/led_indicator.c/h` | DevKitC GPIO48 板载 WS2812B RGB 状态指示 |

## HID 输入映射

权威表见 [/CLAUDE.md](../../CLAUDE.md) "HID Key Mappings"，简要：

| 输入 | HID 按键 |
|---|---|
| Action Button 按 | Enter |
| EC11-L 旋转 / 按 | ↑/↓ / F1 |
| EC11-R 旋转 / 按 | →/← / F2 |
| NFC 卡 (NDEF Text) | `<payload>\n` |
| NFC 卡 (UID 兜底) | `NFC:<UID_HEX>\n` |

> GPIO 号 / 连接器映射见 CLAUDE.md "GPIO Pin Assignments"，本文不重复。

## LED 行为

DevKitC GPIO48 板载 RGB（不外接 LED）：

| 事件 | 颜色 |
|---|---|
| 启动完成 | 绿色闪烁 |
| 按钮按下 | 红色 |
| NFC 识别中 | 蓝色 |

## 构建与烧录

```bash
get_idf                                    # 激活 ESP-IDF 环境
idf.py set-target esp32s3                  # 首次
idf.py build
idf.py -p /dev/cu.usbmodem* flash monitor  # 走 DevKitC UART USB-C 烧录，不走 OTG USB-C
```

> ⚠️ **烧录走 UART USB-C，不要走 OTG USB-C** — 板上 USB D+/D- 同时连到 J5 (dongle) 和 native USB-C 焊盘，外部插会冲突。详见 CLAUDE.md。

## 已知技术债

详见 [/CLAUDE.md](../../CLAUDE.md) "Known Limitations / Technical Debt"：

- NFC SPI 时钟暂用 1MHz（PCB 版可尝试拉回 5MHz）
- HID 多键并发已修复（2026-05-08 `s_pressed_keys[6]` + mutex）
- NFC 启动失败容错已实现（2026-05-10 warn 不 abort）
- sdkconfig 已升级 N16R8（2026-05-08 16MB QIO + 8MB Octal PSRAM）

## 硬件需求

详见 [/CLAUDE.md](../../CLAUDE.md) "Hardware Target (V4)" + [V4 硬件参考资料](../../project/v4/shared/硬件参考资料.md)。

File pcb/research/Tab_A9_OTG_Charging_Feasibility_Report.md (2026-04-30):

# CosmoRadio V4 专用 Tab A9 半主动 USB-C OTG + 充电方案可行性调研报告

## 1. 方案工作原理与机制分析

在 USB-C 和 Android 体系下，实现平板作为 USB Host（控制 ESP32-S3）同时接受外部充电，涉及到 USB 角色协商和电源路径管理的复杂机制。

### 1.1 标准行为与设备特定行为
*   **标准 USB-C DRP (Dual Role Port) 行为**：标准的 USB-C 接口通过 CC (Configuration Channel) 引脚进行角色协商。供电端（Source）在 CC 引脚上提供上拉电阻（Rp），受电端（Sink）提供下拉电阻（Rd，5.1kΩ）。双角色端口（DRP）在未连接时会交替呈现 Rp 和 Rd。当平板作为 USB Host 时，标准行为是它必须作为供电端（Source），向外输出 5V VBUS，此时其内部 CC 逻辑呈现 Rp [1]。
*   **SimulCharge / ACA (Accessory Charger Adapter) 机制**：在早期的 Micro-USB 时代，USB BC 1.2 规范定义了 ACA 机制，通过在 ID 引脚上接特定阻值的电阻（如 124kΩ 或 36.5kΩ），允许设备同时作为 USB Host 并接受充电 [2]。
*   **设备特定行为（Samsung 专有实现）**：在 USB-C 时代，虽然 USB PD 规范支持 Power Role Swap（电源角色交换）和 Data Role Swap（数据角色交换），但这需要完整的 PD 协议栈支持。对于低成本的半主动方案（不使用 PD 芯片），三星等厂商在底层固件中保留了类似 ACA 的模拟检测逻辑，或者允许在特定的 CC 电阻组合及 VBUS 强制注入时，触发“Host 模式下充电”的隐藏状态。这属于**高度设备特定**的行为，严重依赖于平板的内核驱动和充电 IC 固件 [3]。

## 2. 可行电路拓扑建议

针对“低复杂度、可集成到 PCB、不使用完整 PD 固件栈”的需求，建议采用以下半主动注入拓扑：

### 2.1 核心连接关系
1.  **外部充电器 VBUS 注入**：外部 5V 电源通过一个低压降的肖特基二极管（如 SS14 或 SS24）或者 P-MOSFET 理想二极管电路，注入到连接平板的 VBUS 线上。
2.  **平板端 CC 引脚配置**：
    *   在连接平板的 USB-C 插头的 CC 引脚上，需要配置特定的电阻网络来“欺骗”平板。
    *   **常规尝试**：接 5.1kΩ 下拉电阻（Rd）到地，使平板认为连接了充电器（进入 Sink 模式接受充电），同时强行在 D+/D- 上进行数据通信。
    *   **三星特定尝试（模拟 ACA）**：部分三星设备可能需要特定的 Rp 上拉（例如 56kΩ 到 5V）或者在 CC 线上施加特定电压，配合 D+/D- 上的设备连接，才能触发 SimulCharge 模式。
3.  **ESP32-S3 端**：ESP32 的 USB D+/D- 直接连接到平板的 D+/D-。ESP32 的供电可以直接取自外部注入的 5V VBUS。
4.  **防反灌保护**：**必须**在平板 VBUS 和外部充电器 VBUS 之间加入隔离。如果不加隔离，当外部电源断开时，平板会试图向外输出 5V（Host 模式默认行为），导致平板电池被外部电路迅速抽干 [4]。

### 2.2 推荐验证拓扑（第一版，已修正）
*   **最小拓扑**：`Tab_A9_VBUS` 直接作为 `SYS_5V` 给 ESP32 供电。`VBUS_IN -> SS34 -> Tab_A9_VBUS/SYS_5V`。无外部电源时，平板 Host 给 ESP32 供电；有外部电源时，外部 5V 通过 SS34 尝试注入同一节点。该拓扑只需要 1 颗 SS34。
*   **完整诊断拓扑**：验证板单独定义一个 `SYS_5V` 轨道给 ESP32 供电。`SYS_5V` 同时支持两种来源：
    *   无外部电源时：`Tab_A9_VBUS -> SS34/理想二极管 -> SYS_5V -> ESP32_5V`，由平板 Host 供电给 ESP32。
    *   有外部电源时：`VBUS_IN -> SS34/理想二极管 -> SYS_5V -> ESP32_5V`，由充电器供电给 ESP32。
*   **平板充电注入路径**：`VBUS_IN -> SS34/限流/eFuse -> Tab_A9_VBUS`，尝试让平板在 Host 模式下接受外部 VBUS。
*   **CC 引脚**：平板侧 CC1/CC2 尝试下拉 5.1kΩ 到 GND（基础 Sink 测试），或预留焊盘以便测试悬空/上拉。
*   **数据线**：ESP32 D+/D- 直连平板 D+/D-（注意 USB 2.0 走线尽量等长）。

## 3. 最小样板验证步骤

在进行 PCB 投板前，必须使用洞洞板或简单的转接板进行验证。

### 3.1 验证准备
*   准备一个 USB-C 母座（接外部电源）、一个 USB-C 公头（接 Tab A9）、一个 ESP32-S3 DevKit。
*   准备万用表、示波器、低压降肖特基二极管（如 SS24）、5.1kΩ 电阻。

### 3.2 测试步骤与测量项
1.  **基础充电测试**：只连接外部 5V 和 CC 下拉电阻到平板，万用表测量平板 VBUS 电压，确认平板是否显示充电。
2.  **数据连通测试**：在步骤 1 基础上，将 ESP32 的 D+/D- 接入，观察 ESP32 是否成功枚举为 HID 设备。
3.  **无外部电源 OTG 测试**：断开外部 5V，确认平板 `Tab_A9_VBUS` 能通过隔离路径拉起 `SYS_5V`，ESP32 能上电并枚举为 HID。
4.  **VBUS 冲突测试（关键）**：断开外部 5V，万用表测量外部充电输入端，确认平板输出的 VBUS 没有反灌到充电器输入。接入外部 5V 后，确认 `SYS_5V` 来源切换不导致 ESP32 掉电。
5.  **枚举中断测试**：在 ESP32 正常工作时，插拔外部 5V 电源，观察 ESP32 的 HID 连接是否会断开重连。

### 3.3 通过/失败标准
*   **通过**：Tab A9 显示充电（即使是慢充），且 ESP32 稳定枚举为 HID 并能发送数据；插拔充电器不导致 ESP32 掉线或仅有短暂可恢复的掉线。
*   **失败**：Tab A9 拒绝充电；或者充电时无法识别 ESP32；或者外部电源断开时，平板反向供电导致系统不稳定。

## 4. Tab A9 兼容性实测证据

针对 Samsung Galaxy Tab A9 (SM-X110) 的 SimulCharge 兼容性，调研结果**非常不乐观**。

1.  **LAVA 官方兼容性列表**：LAVA 是提供 SimulCharge 适配器的权威厂商。在其 Charge-Plus 兼容性列表中，**未列出**基础版 Tab A9 (SM-X110)。列表中仅提到了 Tab A7 Lite、Tab A8 等，且明确指出部分型号（如 Tab A7 Lite SM-T220）存在严重的电流限制 bug（电量不同时拉取的电流不同，甚至低至 0.5A），并建议**不要使用** [5]。
2.  **用户社区反馈**：在三星社区和 Reddit 上，多位用户反馈 Tab A9 和 A9+ 无法在使用普通 USB-C Hub 时同时进行 OTG 和充电。有用户明确表示“连接 USB-C 输入会点亮适配器，Android 显示正在充电，但无法与外设工作” [6]。
3.  **底层限制原因**：LAVA 的技术博客指出，如果移动设备没有实现完整的 USB-C PD 规范（Power Delivery），就无法与适配器协商电源契约，从而无法实现同时供电和数据传输 [7]。Tab A9 作为入门级平板，其 USB-C 接口仅支持 USB 2.0 且大概率**阉割了完整的 PD 角色交换功能**。

## 5. 可采购器件建议 (LCSC/立创商城)

为了控制 BOM 复杂度，建议采购以下基础器件进行验证：

*   **肖特基二极管（防反灌）**：
    *   **SS24** (Slkor / 长电)：2A，40V。价格极低（约 0.05 RMB），适合基础验证，但压降较大（约 0.5V）。
    *   **SS34**：3A 版本，余量更大。
*   **P-MOSFET（替代肖特基，降低压降）**：
    *   **AO3401A** (AOS / 长电)：-4.2A，-30V，SOT-23 封装。常用于简单的 VBUS 开关和防反接电路，导通电阻低 [8]。
*   **ESD 保护**：
    *   **USBLC6-2SC6** (ST / 各种国产替代)：专为 USB 2.0 D+/D- 设计的超低电容 ESD 阵列，SOT23-6 封装。

## 6. 风险清单

*   **平板拒绝充电 / 充电电流不足**：由于缺乏 PD 协商，平板可能只以默认的 500mA 甚至拒绝充电。
*   **枚举中断**：在插拔外部充电器时，VBUS 电压的波动可能导致 ESP32 重新启动或 USB 重新枚举，导致操作中断。
*   **反灌风险**：如果防反灌二极管失效或 P-MOSFET 栅极控制逻辑错误，外部 5V 和平板输出的 5V 发生冲突，可能烧毁平板接口。
*   **CC 配置错误**：错误的电阻值可能导致平板进入错误的模式（如纯供电模式），完全无法识别设备。

## 7. 最终结论与建议

**结论：针对 Tab A9 (SM-X110) 做纯硬件的“半主动”验证小板，风险极高，成功率较低，但考虑到项目成本限制，值得进行一次低成本的“死马当活马医”式验证。**

原因在于，大量证据表明 Tab A9 缺乏完整的 PD 协议支持，三星很可能在固件层面屏蔽了简单的电阻欺骗法。如果基础的下拉/上拉验证失败，则说明该平板**必须**依赖带 PD 芯片的复杂方案（如通过 FUSB302 等芯片进行角色交换协商），这将违背“低复杂度”的初衷。

### 第一版验证板原理图级连接清单：

1.  **VBUS_IN (外部 5V)** 连接到 **Diode_Anode** (肖特基阳极)。
2.  **Diode_Cathode** (肖特基阴极) 连接到 **Tab_A9_VBUS**。
3.  **最小拓扑**：**Tab_A9_VBUS** 直接连接到 **ESP32_5V_IN**，此时 **Tab_A9_VBUS** 同时也是 **SYS_5V**。
4.  **完整诊断拓扑**：**Tab_A9_VBUS** 通过第二路 SS34/理想二极管连接到 **SYS_5V**，保证无外部电源时平板能给 ESP32 供电。
5.  **完整诊断拓扑**：**VBUS_IN** 通过第三路 SS34/理想二极管连接到 **SYS_5V**，保证有外部电源时充电器给 ESP32 供电。
6.  **SYS_5V** 连接到 **ESP32_5V_IN**。
7.  **Tab_A9_CC1** 和 **Tab_A9_CC2** 各接一个 **5.1kΩ** 电阻到 **GND**（预留断开跳线）。
8.  **Tab_A9_D+** 直连 **ESP32_D+**。
9.  **Tab_A9_D-** 直连 **ESP32_D-**。
10.  所有设备的 **GND** 共地。

*建议先用切断 VBUS 线的 USB 数据线配合面包板进行测试，若步骤 3.2 中的测试均失败，则应果断放弃半主动方案，考虑更换平板型号或接受无法边充边用的现实。*

---
### 参考文献
[1] Texas Instruments. A Primer on USB Type-C and Power Delivery Applications.
[2] StackExchange. Can an Android tablet serve as USB Host and be charged simultaneously.
[3] XDA Forums. Guide..OTG USB HOST and CHARGING at same time for Galaxy tabs.
[4] Reddit. USB-C Prevent back powering in Host OTG-Mode.
[5] LAVA Accessory. Charge-Plus Compatibility List.
[6] Samsung Community. Galaxy Tab A9 USB and charging at the same time.
[7] LAVA Blog. Why Some USB-C Mobile Devices Can't Do Simultaneous Power and Data.
[8] LCSC. AO3401A Datasheet and Pricing.

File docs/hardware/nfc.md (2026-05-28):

# CosmoRadio V4 — NFC 模块方案

NFC 文档已迁移到 V4 交付包，后续只维护这些文件：

- `project/v4/shared/平板对接协议.md`
- `project/v4/shared/硬件参考资料.md`

迁移原因：

- 旧文档包含早期 `#<payload>` 协议、NTAG215 推荐和旧 GPIO 示例，已不符合最终交付状态。
- V4 交付包是客户验收文件夹，NFC 模块、标签、写卡规则、接线和验收说明应以交付包文档为准。

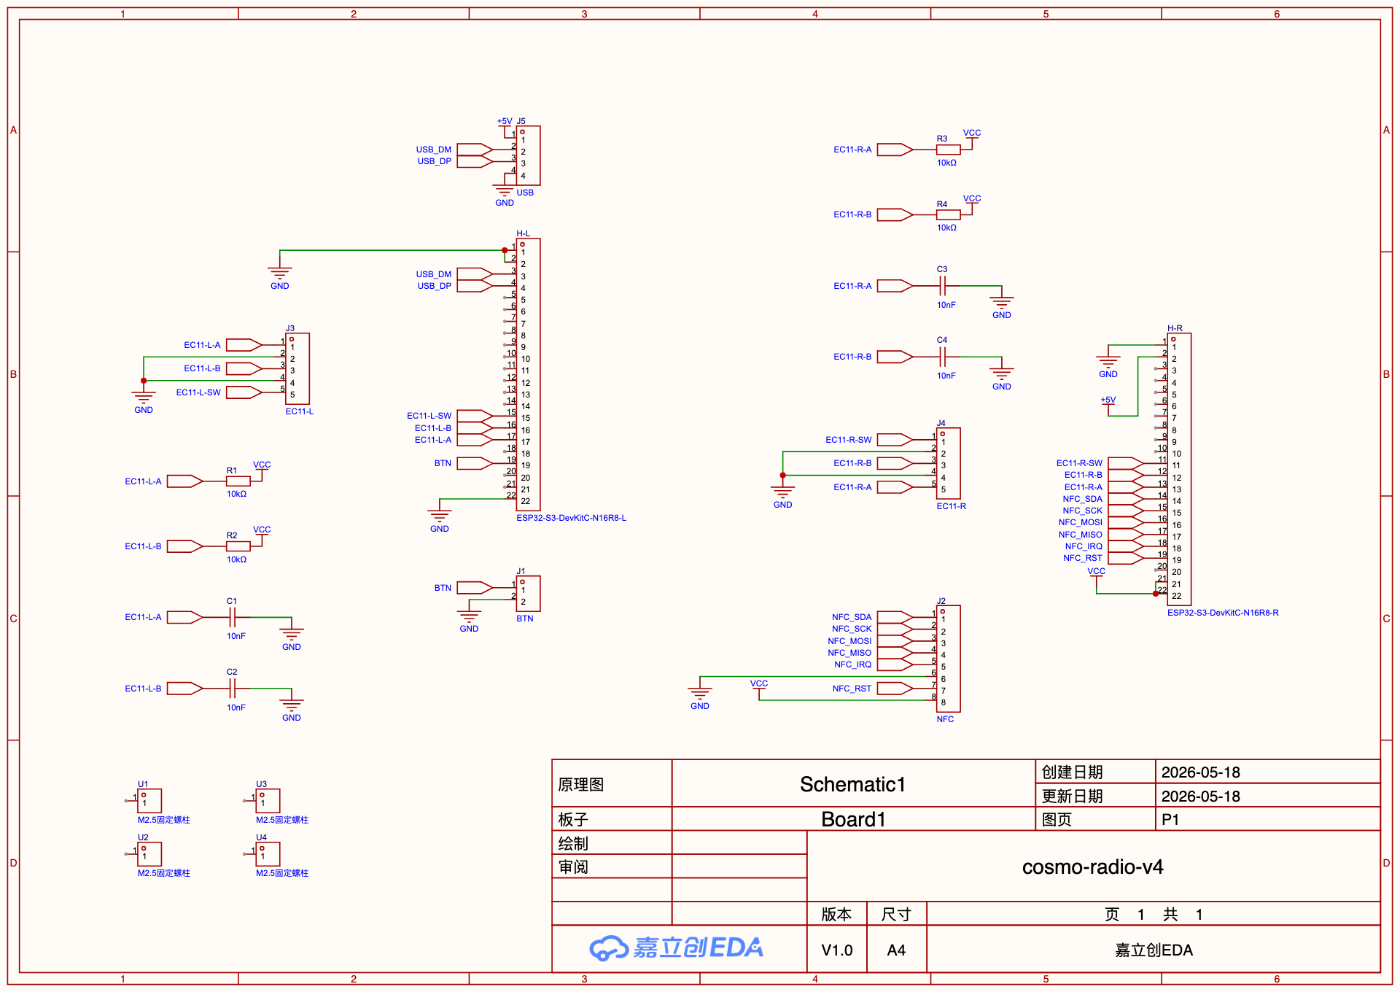
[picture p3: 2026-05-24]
pcb/cosmoradio-v4-jlceda/cosmoradio-v4-r1.0-schematic.png

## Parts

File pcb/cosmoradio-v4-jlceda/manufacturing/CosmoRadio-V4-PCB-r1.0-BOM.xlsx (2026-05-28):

No. | Quantity | Comment | Designator | Footprint | Value | Manufacturer Part | Manufacturer | Supplier Part | Supplier
1 | 4 | 10nF | C1,C2,C3,C4 | C0805 | 10nF | CL21B103KBANNNC | SAMSUNG(三星) | C1710 | LCSC
2 | 1 | ESP32-S3-DevKitC-N16R8-L | H-L | HDR-TH_22P-P2.54-V-F |  | ESP32-S3-DevKitC-N16R8-L | Bossie(博锡) | C18078140 | LCSC
3 | 1 | ESP32-S3-DevKitC-N16R8-R | H-R | HDR-TH_22P-P2.54-V-F |  | ESP32-S3-DevKitC-N16R8-R | Bossie(博锡) | C18078140 | LCSC
4 | 1 | BTN | J1 | CONN-TH_2P-P2.50-XH2.54-2P |  | BTN |  | C9900008615 | LCSC
5 | 1 | NFC | J2 | CONN-TH_8P-P2.50-XH2.54-8P |  | NFC |  | C9900000730 | LCSC
6 | 1 | EC11-L | J3 | CONN-TH_5P-P2.50_JST_B5B-XH-A-M |  | EC11-L | JST | C495550 | LCSC
7 | 1 | EC11-R | J4 | CONN-TH_5P-P2.50_JST_B5B-XH-A-M |  | EC11-R | JST | C495550 | LCSC
8 | 1 | USB | J5 | CONN-TH_4P-P2.50-XH2.54-4P |  | USB |  | C9900008616 | LCSC
9 | 4 | 10kΩ | R1,R2,R3,R4 | R0805 | 10kΩ | 0805W8J0103T5E | UNI-ROYAL(厚声) | C25612 | LCSC
10 | 4 | M2.5固定螺柱 | U1,U2,U3,U4 | SMD_BD5.0-L5.0-D2.6 |  | M2.5固定螺柱 |  | C9900023457 | LCSC

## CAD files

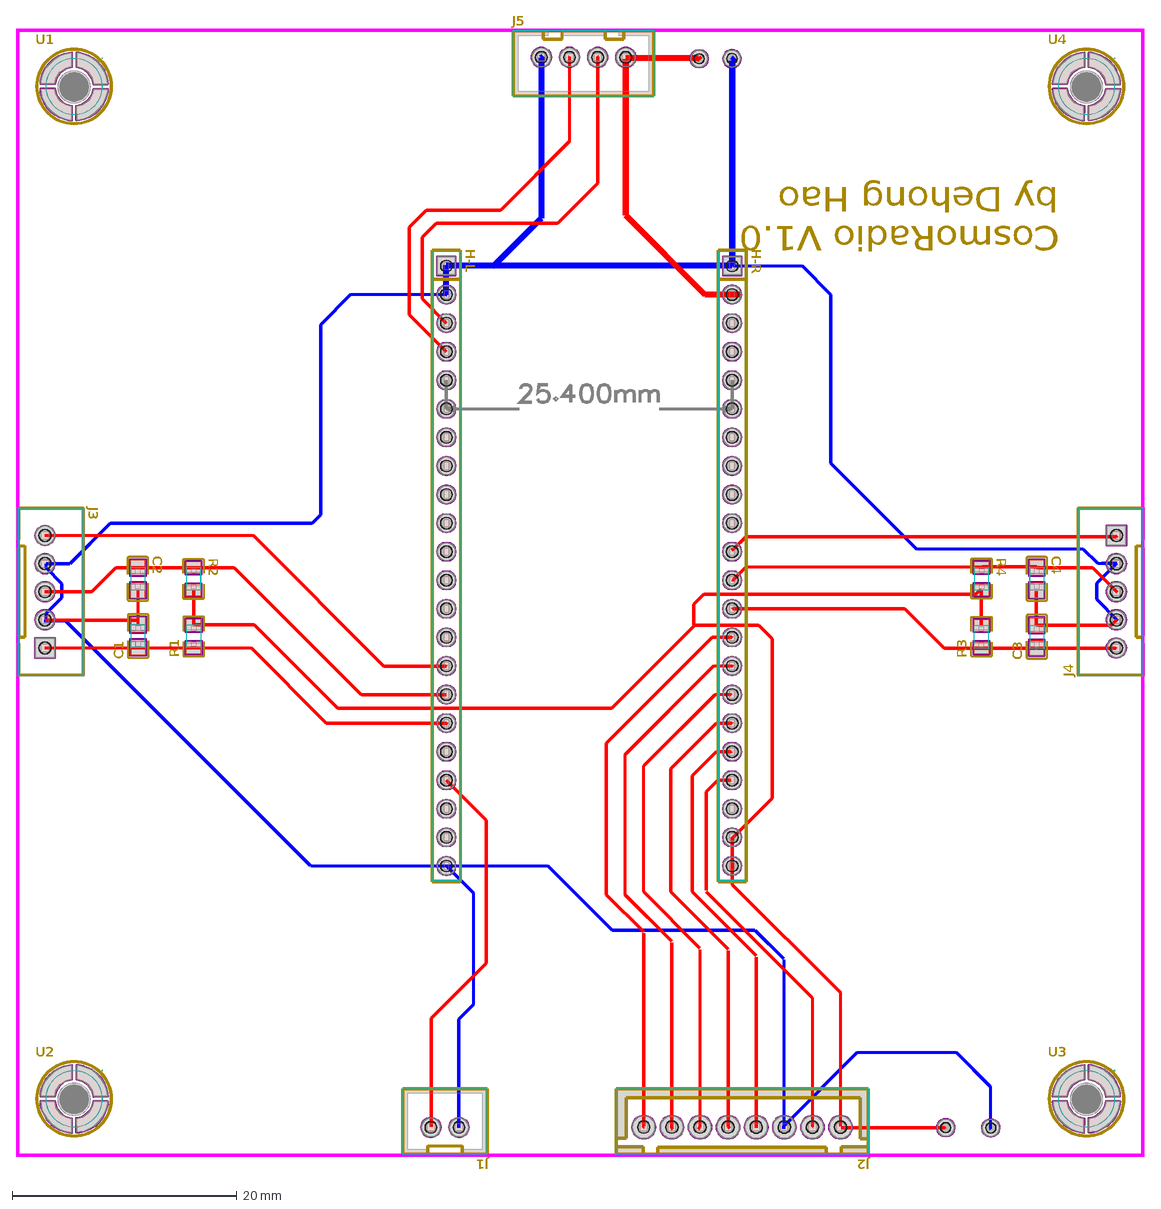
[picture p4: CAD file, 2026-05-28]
pcb/cosmoradio-v4-jlceda/manufacturing/CosmoRadio-V4-PCB-r1.0-BoardOutline.dxf
CosmoRadio V1.0
by Dehong Hao
C1
C2
C3
C4
H-L
H-R
J1
J2
J3
J4
J5
R1
R2
R3
R4
U1
U2
U3
U4

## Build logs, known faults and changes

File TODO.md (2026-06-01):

# CosmoRadio V4 — TODO

> **✅ 第四期已结项（2026-06-01）** — 技术验证 2026-05-22 完成，2026-05-31 客户收到成品交付，2026-06-01 开票收款 ¥5,000（累计 ¥31,000 全部结清）。见 [V4 资料包](project/v4/shared/先读说明.md)。
> post-delivery 回归已于 2026-05-24 结项确认完成；剩余仅为 PCB 制造文件归档 + r1.1 优化建议。
>
> 第四期：2026-04-01 启动 → 2026-04-02 取消 → 2026-04-29 重启
> 当前交付：技术方案验证 + 单套原型制作
> 项目文档：[project/](project/)
> 合同价：¥5,000 | 目标交付：2026-05-20 左右（实际 2026-05-22 完成）

## 2026-05-07 整体技术方案验证完成 ✅

电气、固件、NFC 协议在万能板飞线版上**端到端跑通**：

- ESP32-S3 DevKitC N16R8 主控 + 4 路 XH2.54 连接器（双 EC11、Action Button、NFC）（注：飞线版当时 J 编号跟 r1.0 PCB 不同，详见 CLAUDE.md）
- 拆解一分二 OTG + 充电线材内置子板，平板 USB Host + 充电同时工作
- 固件 V4 GPIO 全部跑通：Action Button、双 EC11 旋转 + 按压、板载 RGB
- NFC 链路：RC522 SPI（1MHz）→ 读 NTAG215 UID + NDEF Text Record → HID 键入 `#<payload>\n`
- 协议契约：NDEF Text 主路径 / `NFC:<UID>` 兜底 / 1.5s 同卡去重
- 端到端独立验证：iPhone NFC Tools 写入 "112358" → ESP32 读到字节级一致 UID + payload

**剩余工作集中在 PCB 设计 + 结构件 + 整机装配**，不再有方案级未知风险。

---

## 2026-05-08 今日双线并行 + PCB 前最后一项验证

| 线 | 谁 | 内容 |
|----|----|----|
| 固件 | Claude | 彻底优化升级到 V4（A 类技术债清理 + 代码整理） |
| 结构 | Dehong | NFC 模块 + 长按条按钮模块结构设计 + 历史结构改进 |

✅ **2026-05-18 PCB Plan v2 锁定**：USB 互联走线方案确定为"OTG dongle 拆 USB-A → 4 飞线 → J5 4P → DevKitC 排针"，详见 `~/.claude/plans/iridescent-snuggling-planet.md`。

---

## 2026-05-22 PCB r1.0 实焊 + 固件验证完成 ✅

最终走 JLCEDA Pro 手绘 r1.0，验证版工程已归档 `pcb/cosmoradio-v4-jlceda/`。早期 KiCad Plan v2 备选未使用，已删除（见 git 历史）。

- ✅ PCB 打板 + 焊接 + DevKitC 插入 + JST 端子线压接
- ✅ 双 EC11 + Action Button + NFC + USB HID 全链路验证通过（两台板子并排测）
- ✅ EC11-R 右旋钮初次表现异常（任意方向都是 CW、按下变 CCW）——根因：J4 引脚顺序在原理图里画成跟 J3 镜像，物理 EC11 端子线序错位
- ✅ 固件层 walkaround：`main/input_handler.c` 重新指派 `GPIO_ENC2_A/B/SW`，并 swap A↔B 让两个旋钮"向内拨"方向一致——硬件不返工
- 📌 PCB r1.1（未启动）：把 J4 改成跟 J3 对称的 `[A, GND, B, GND, SW]`，去掉固件 walkaround
- 📌 顺便把原理图里几个标错的"GND/+5V"标签（H-L pin 1、H-R pin 1/pin 2）改正——这些 net 物理上不是电源，r1.0 是因 PCB 走线没真连才幸免

详见 [CLAUDE.md "PCB r1.0 EC11-R 接线 walkaround"](CLAUDE.md#pcb-r10-ec11-r-接线-walkaround2026-05-22)。

---

## 2026-05-28 固件安全回归修复 ✅

- Action Button / EC11 SW 改为中断触发 + 10ms 物理电平复核，释放沿丢失时仍会补发 key up ✅ 2026-05-28
- HID report 提交增加 endpoint ready 等待和后台 retry，避免 press 后 release report 因 endpoint busy 丢失 ✅ 2026-05-28
- NFC start 失败后改为后台 5s 重试，避免 RC522 上电慢导致开机后永久不可用 ✅ 2026-05-28
- 已在 PCB r1.0 装机状态烧录验证：RC522 初始化成功，Action Button `pressed` / `released` 连续成对出现 ✅ 2026-05-28

---

## 当前范围（2026-04-29 重启）

- [x] 与 Arthur 达成重启协议：V4 缩小为技术方案验证和单套原型制作
- [x] 合同价确认：¥5,000
- [x] 目标交付时间确认：2026-05-20 左右
- [x] **验证 PCB 载板设计路径** ✅ 2026-05-07（飞线版跑通，剩 KiCad 落版）
- [x] 完成一套可演示原型，不再按 4 套整机 + 8 套电子套件交付 ✅ 2026-05-22

---

## 关键待办

### USB 互联走线 ✅ 2026-05-18 已锁定（Plan v2）

> 方案：OTG dongle (YK16-09E V1) 拆 USB-A 母座 → 4 根 AWG28 飞线 → J5 (XH2.54 4P) → DevKitC 排针 GPIO19/20 + 5V/GND。
> 详见 [`docs/hardware/otg-adapter.md`](docs/hardware/otg-adapter.md) + `~/.claude/plans/iridescent-snuggling-planet.md`。

- [x] OTG 子板选型 (YK16-09E V1) ✅ 2026-05-06
- [x] USB 走线方案确认（J5 4P → DevKitC 排针，无中间 USB-C 跳线）✅ 2026-05-18

### PCB 载板设计 ✅ 2026-05-22 r1.0 实焊验证完成

> 最终路径：JLCEDA Pro 手绘 r1.0，验证版工程 `pcb/cosmoradio-v4-jlceda/`。KiCad Plan v2 备选未使用，已删除（git 历史可追溯）。

- [x] DevKitC N16R8 排针间距确认（22.86mm = 9 × 2.54mm pitch）✅ 2026-05-18
- [x] 用两条 1×22 单排母（不用 2×22 双排）✅ 2026-05-18
- [x] 加 EC11 RC 去抖网络（4× 10kΩ + 4× 10nF 0805）✅ 2026-05-18
- [x] Plan v2 KiCad 备选方案（circuit-synth + pcbnew API + Freerouting，Gerber + BOM + 渲染图全套）✅ 2026-05-18 — 未上 JLCPCB，被 P1.epro2 替代
- [x] JLCEDA Pro 手绘 r1.0 原理图 ✅
- [x] r1.0 PCB 打样 + 焊接 ✅ 2026-05-22
- [x] r1.0 双板并排功能验证 ✅ 2026-05-22
- [ ] **PCB r1.1**：修正 J4 镜像、修正 H-L pin 1 / H-R pin 1·pin 2 的 GND/+5V 误标，并去掉固件 walkaround

### USB-C 板载集成评估 ✅ 2026-05-18 关闭 — OTG dongle 方案替代
> ~~原方案 B：PCB 双 USB-C 座 + 被动 SS34 VBUS 注入~~ → 2026-04-30 实测失败（Tab A9 PD 协议不接受）
> **最终方案**：外购 OTG dongle (YK16-09E V1) 拆 USB-A 内置，详见 [docs/hardware/otg-adapter.md](docs/hardware/otg-adapter.md)
> ~~历史选型详情~~ → [docs/hardware/usb.md](docs/hardware/usb.md) (已标记历史文档)

- [x] 研究 USB-C 母座直焊 PCB 方案（CC 引脚配置、ESD 保护）→ 鹏宇 6P 大电流转接板，板载 5.1kΩ CC pull-down
- [x] 研究 USB 信号分流芯片（如 USB Hub IC），实现板载一分二 → 不需要 Hub IC，被动 VBUS 注入即可
- [x] 对比方案成本：USB-C 母座 (~¥3) + Hub IC (~¥5) + 被动元件 vs 当前 ¥57.80 → ¥3.12/套 vs ¥57.80/套
- [x] 评估 JLCPCB SMT 贴片可行性（Hub IC 封装是否支持）→ 无需 SMT，DIP 转接板直插
- [x] **被动 SS34 注入实测**（2026-04-30）→ 失败，6P 转接板 + SS34 无法让 Tab A9 同时进入 Data Host + Power Sink，弃用为主线
- [x] **采购一分二 OTG + 充电线材**（2026-05-06）→ 已购买多种型号，测试出一种比较理想的可作为内置子板基准
- [x] **手工万能板原型集成**（2026-05-06，[图片](docs/assets/v4-handmade-prototype-2026-05-06.jpg)）→ ESP32-S3 DevKitC + 拆解后的一分二小板 + 5 路 XH2.54 连接器已焊出
- [x] 回归测试：HID 枚举 / 充电接入 / 旋钮 / 按钮 / NFC（PCB r1.0 上完成 2026-05-22）
- [ ] 整机长时间热稳定 + 充电链路 2h 测试（需要 Tab A9 到货后做）

### 按钮机构
> 选定方案：键盘轴 + 6.25U 卫星轴空格键，长度 ~10cm
> 状态：物料预计 04-02/03 到货，待手感测试
> ⚠️ **测试机变更（2026-05-06）**：原 R4 Pad（Arthur 寄来）因操作失误已损坏，临时使用安卓手机替代验证 USB HID + 充电链路。Tab A9 行为兼容性需在拿到新 Pad 后再回归一遍。

- [ ] 收到 Arthur 寄来的 Pad → 装配按钮测试手感
- [ ] Kailh BOX 轴 + 6.25U 卫星轴原型测试
- [ ] 3D 打印键帽适配（与 Arthur 外壳顶部模块配合）
- [ ] 行程验证 ≥ 3mm，稳定性测试
- [ ] **新 Tab A9 到货后**：回归 HID + 充电链路（当前在安卓手机上验证）

### NFC 模块
> 方案设计完成 ✅ 2026-04-01，详见 [docs/hardware/nfc.md](docs/hardware/nfc.md)
> 驱动库：`abobija/esp-idf-rc522` v3.4.3 (ESP Component Registry)
> 通信协议：HID 键盘逐字符键入 `NFC:<UID_HEX>\n`，平板端解析
> ✅ **NFC 数量已确认（2026-05-06）**：1 个 RC522 mini，最终方案，不再讨论。

- [x] 方案调研：模块选型、标签选型、驱动库评估、可行性分析 ✅ 2026-04-01
- [x] 确定安装位置：**外壳顶部模块内侧**（天线朝上） ✅ 2026-04-01
- [x] J4 连接器 pinout 确认（8P，与模块物理丝印一一对应） ✅ 2026-04-01
- [x] NFC 数量决策：1 个 ✅ 2026-05-06
- [x] RC522 mini SPI 驱动开发（ESP-IDF，abobija/rc522 v3.x） ✅ 2026-05-07
- [x] NTAG215 UID 读取 → HID 字符串键入实现 ✅ 2026-05-07
- [x] **NDEF Text Record 解析**：从卡上读出用户写入的字符串 ✅ 2026-05-07
- [x] 同卡 1.5s 去重（应对 RC522 心跳抖动） ✅ 2026-05-07
- [ ] 天线读取距离测试（穿透 3D 打印壁厚 2mm）— 留到外壳打印后

### 固件迁移
- [x] **设计 V4 引脚接线方案**（CLAUDE.md GPIO 表定稿，与万能板焊接一致） ✅ 2026-05-06
- [x] SuperMini → DevKitC N16R8 GPIO 重映射（input_handler.c / led_indicator.c） ✅ 2026-05-06
- [x] 新增 NFC SPI 模块（SPI2 GPIO Matrix，1MHz） ✅ 2026-05-07
- [x] 新增按钮 + 双 EC11 SW 处理 ✅ 2026-05-06
- [x] input_handler 扩展：NFC 事件 → `nfc_handler.c` 独立模块 + HID 字符串键入 ✅ 2026-05-07
- [x] 万能板上烧录验证：旋钮 / 按钮 / NFC 全链路 ✅ 2026-05-07
- [x] CLAUDE.md GPIO 分配表确认 ✅ 2026-05-06
- [x] `sdkconfig.defaults` 更新：N16R8 16MB flash + octal PSRAM ✅ 2026-05-08
- [x] HID Key Report 多键并发支持（`pressed_keys[6]` 状态数组 + mutex，消除 NFC 字符串注入与用户按键的竞态） ✅ 2026-05-08
- [x] NFC 启动失败容错：`nfc_handler_init/start` 失败时只 warning 不 abort，裸板（无 RC522）演示不再 reboot loop ✅ 2026-05-10
- [x] 按钮释放安全复核 + HID key-up 重试 + NFC 后台启动重试 ✅ 2026-05-28
- [ ] NFC SPI 时钟从 1MHz 拉回 5MHz（需 PCB 焊好后验证，飞线版受 RF 噪声干扰）

### 旋钮与协议
> ✅ 协议定稿（2026-05-07，2026-05-15 简化）：详见 [README.md 交互设计](README.md#交互设计) 和 [CLAUDE.md HID Key Mappings](CLAUDE.md)
> NFC 主路径：固件读 NDEF Text → 原样键入 + Enter（无前缀，2026-05-15 起去掉 `#`）；UID 兜底用 `NFC:` 前缀

- [x] 编写旋钮 + NFC HID 协议（CLAUDE.md HID Key Mappings + NFC Tag 内容编码契约） ✅ 2026-05-07

### 外壳适配
> Arthur 已展示概念图，基本还原效果。设备可能两边各宽 1cm 增加安装灵活性。
> 充电口需留位，可水平插入。顶板螺丝固定，M2.5×10 平头内六角。
> **2026-05-08 起 Dehong 自己负责**：NFC 模块结构 + 长按条按钮模块结构 + 历史结构改进。

- [ ] **NFC 模块结构设计**（Dehong）：天线朝外、与 PCB 安装位对齐、走线通道
- [ ] **长按条按钮模块结构设计**（Dehong）：键盘轴 + 6.25U 卫星轴空格键，按压行程 + 装配方式
- [ ] **历史结构改进**（Dehong）：复盘 R1-R3 装配中暴露的问题点
- [ ] 与 Arthur 对接 Fusion 360 模型 (`cosmo-radio-v4-arthur`)
- [ ] 模块化验证：主体 / 顶部 / 背板 三件可独立打印
- [ ] PCB 安装孔位对齐（4 × M2.5）
- [ ] 线缆走线通道确认（取决于 USB 互联走线方案是否落地）
- [ ] Arthur 修改设计：充电口位置、设备宽度调整 → 打印小号模型验证
- [ ] NFC 位置确定后，协调另一侧用途（指示灯 vs 留空）

### 成本核算
> 单套估算 ¥79（不含线材）：主控板 ~¥32 (40%)，按钮+卫星轴 ~¥13，NFC IC ~¥13，底部 PCB 较便宜

- [x] 04-29 重启后合同价调整为 ¥5,000，原 12 套 ¥13,000 报价只作为历史参考
- [ ] 精确估算单套电路成本（待 PCB 设计定稿）
- [ ] 精确估算整机成本（含 3D 打印 + 组装工时）
- [ ] 重新估算单套原型的材料、PCB 打样、工时成本

### 组装与交付
- [ ] 1 套电子件：PCB 焊接 + 连接器 + 功能测试
- [ ] 1 套完整原型：打印 + 装配 + 整机测试
- [ ] 编写技术验证记录（PCB、USB-C、按钮、NFC、固件）
- [ ] 交付文件上传飞书

---

## 重启协议 2026-04-29（与 Arthur）

关键决策：
1. **范围**：仅做技术方案验证和单套原型制作
2. **报价**：¥5,000
3. **目标交付**：2026-05-20 左右
4. **核心挑战**：PCB 设计与验证
5. **合作定位**：保留和 Arthur 的持续硬件合作，不恢复原 4+8 批量交付合同

---

## 会议纪要 2026-04-01（与 Arthur/纪晟）

关键决策：
1. **音响**：使用平板自带音响，不外接
2. **按钮**：键盘轴 + 6.25U 卫星轴空格键（~10cm），物料预计 04-02/03 到
3. **NFC 数量**：2026-05-06 已确认最终使用 1 个 RC522 mini
4. **螺丝**：M2.5×10 平头内六角
5. **旋钮按压**：EC11 SW 引脚会接线，功能可选不用
6. **设备宽度**：暂继续用弯头线，两边各宽 1cm 增加安装灵活性
7. **成本**：单套 ¥79（不含线材），12 套总计约 ¥13,000
8. **付款**：1 周后基础方案验证完成预付 50%

会后 Action Items：
- [ ] Arthur 与杨炜乐讨论 NFC 数量 → 结果告知 Dehong
- [ ] Arthur 寄 Pad → Dehong 收到后测试按钮手感
- [ ] Dehong 估算单套电路和整机价格
- [ ] Arthur 修改设计（充电口位置、宽度）→ 打印小号模型
- [ ] Dehong 编写旋钮 + NFC 协议规范文档

---

## 时间节点

| 日期 | 事项 |
|---|---|
| 04-01 | V4 正式启动，BOM 定稿，第一次需求会议 |
| 04-02 | 原 4 套整机 + 8 套电子套件合同取消 |
| 04-02/03 | 键盘轴物料到货，开始按钮手感测试 |
| 04-04 | Arthur 海运两个铁箱（现有设备） |
| 04-29 | 与 Arthur 重启 V4，范围缩小为技术验证 + 单套原型，合同价 ¥5,000 |
| 05-06 | 万能板飞线原型焊接，V4 GPIO 全部跑通 |
| 05-07 | NFC NDEF Text 解析 + `#<payload>\n` 协议落地，端到端跑通 |
| 05-08 | 固件 V4 彻底优化（sdkconfig + HID 多键并发）+ 结构件设计启动 + USB 互联走线验证 |
| 05-15 | NFC HID 协议简化：NDEF payload 去掉 `#` 前缀，固件 + 文档同步；端到端实卡验证通过（UID `04A38B6A220289`→`004`、`0463DA47220289`→`002`） |
| 05 中旬 | KiCad PCB 设计 + 外壳 3D 模型适配 |
| ~05-20 | 单套原型装配 + 交付技术验证结果 |

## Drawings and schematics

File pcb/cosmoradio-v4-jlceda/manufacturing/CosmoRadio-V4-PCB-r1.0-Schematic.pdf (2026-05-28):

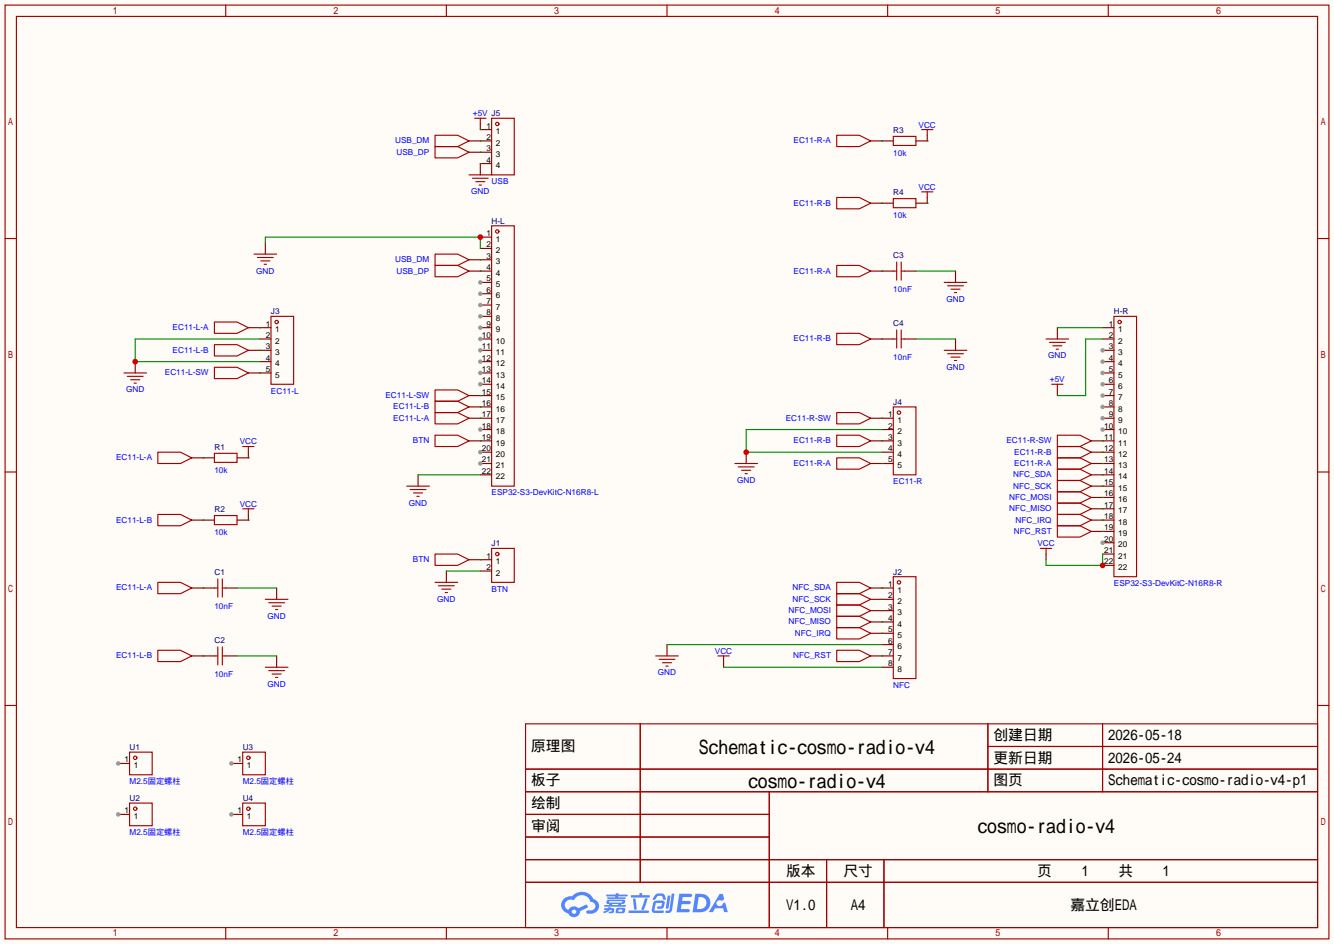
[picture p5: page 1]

原理图 | Schematic-cosmo-radio-v4 | 创建日期 | 2026-05-18

更新日期 | 2026-05-24

板子 | cosmo-radio-v4 | 图页 | Schematic-cosmo-radio-v4-p1
绘制 | | cosmo-radio-v4
审阅

V1.0 | A4 | 嘉立创EDA

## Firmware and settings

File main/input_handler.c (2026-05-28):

/*
 * Input Handler Module Implementation
 * Uses GPIO interrupts + FreeRTOS queue for power-efficient input handling
 */

#include <string.h>
#include "input_handler.h"
#include "freertos/FreeRTOS.h"
#include "freertos/task.h"
#include "freertos/queue.h"
#include "driver/gpio.h"
#include "esp_log.h"
#include "esp_timer.h"
#include "esp_sleep.h"
#include "esp_system.h"  // for esp_restart()

static const char *TAG = "INPUT";

// Pin map: CLAUDE.md "GPIO Pin Assignments" is the single source of truth.
// ENC2 uses a non-obvious GPIO-to-role assignment to compensate for the PCB r1.0
// J4 mirrored pinout and to keep both knobs' perceived direction symmetric — see
// "PCB r1.0 EC11-R 接线 walkaround" in CLAUDE.md before "fixing" these numbers.
#define GPIO_BUTTON     1
#define GPIO_ENC1_A     42
#define GPIO_ENC1_B     41
#define GPIO_ENC1_SW    40
#define GPIO_ENC2_A     18
#define GPIO_ENC2_B     8
#define GPIO_ENC2_SW    17

// All input GPIOs as a mask
#define GPIO_INPUT_MASK ((1ULL << GPIO_BUTTON) | \
                         (1ULL << GPIO_ENC1_A) | (1ULL << GPIO_ENC1_B) | (1ULL << GPIO_ENC1_SW) | \
                         (1ULL << GPIO_ENC2_A) | (1ULL << GPIO_ENC2_B) | (1ULL << GPIO_ENC2_SW))

// Largest GPIO number used (for debounce table sizing)
#define GPIO_MAX_USED   43

// Event queue size (should handle burst of encoder events)
#define EVENT_QUEUE_SIZE 32

// Encoder A/B debounce in microseconds. EC11 A/B lines also have 10k + 10nF RC.
#define ENCODER_DEBOUNCE_US 2000

// Active-low switch debounce. Switch release safety is handled by polling the
// physical GPIO level, so a missed edge cannot leave HID stuck pressed forever.
#define SWITCH_DEBOUNCE_US 10000

// Periodic input reconciliation interval. Keep this at least one FreeRTOS tick;
// otherwise pdMS_TO_TICKS() can round to 0 and create a busy loop.
#define INPUT_POLL_MS 10

// Long press duration for forced restart (15 seconds in microseconds)
#define FORCE_RESTART_HOLD_US (15 * 1000000)

// Internal GPIO event for ISR -> task communication
typedef struct {
    uint8_t gpio_num;
    uint8_t level;
    int64_t timestamp;
} gpio_isr_event_t;

typedef struct {
    uint8_t gpio_num;
    int stable_level;
    int candidate_level;
    int64_t candidate_since_us;
    input_event_type_t press_event;
    input_event_type_t release_event;
    const char *name;
    bool tracks_force_restart;
} active_low_switch_t;

// Module state
static QueueHandle_t s_gpio_evt_queue = NULL;
static TaskHandle_t s_input_task = NULL;
static input_event_callback_t s_callback = NULL;
static volatile int64_t s_last_activity_time = 0;
static volatile bool s_running = false;
static volatile uint32_t s_isr_queue_drops = 0;

// Encoder state tracking (for detent detection)
static uint8_t s_enc1_state = 0;
static uint8_t s_enc2_state = 0;

static active_low_switch_t s_button = {
    .gpio_num = GPIO_BUTTON,
    .stable_level = 1,
    .candidate_level = 1,
    .press_event = INPUT_EVENT_BUTTON_PRESS,
    .release_event = INPUT_EVENT_BUTTON_RELEASE,
    .name = "Button",
    .tracks_force_restart = true,
};

static active_low_switch_t s_enc1_sw = {
    .gpio_num = GPIO_ENC1_SW,
    .stable_level = 1,
    .candidate_level = 1,
    .press_event = INPUT_EVENT_ENC1_SW_PRESS,
    .release_event = INPUT_EVENT_ENC1_SW_RELEASE,
    .name = "ENC1 SW",
    .tracks_force_restart = false,
};

static active_low_switch_t s_enc2_sw = {
    .gpio_num = GPIO_ENC2_SW,
    .stable_level = 1,
    .candidate_level = 1,
    .press_event = INPUT_EVENT_ENC2_SW_PRESS,
    .release_event = INPUT_EVENT_ENC2_SW_RELEASE,
    .name = "ENC2 SW",
    .tracks_force_restart = false,
};

// Button press timestamp for force restart detection
static int64_t s_btn_press_time = 0;

// Last ISR time for each GPIO (for software debounce, indexed by gpio_num).
// Sized to cover the largest GPIO number we attach an ISR to.
static int64_t s_last_isr_time[GPIO_MAX_USED + 1] = {0};

// ISR handler - minimal work, just queue the event
// Note: Keep this as simple as possible to avoid watchdog issues
static void IRAM_ATTR gpio_isr_handler(void *arg)
{
    uint32_t gpio_num = (uint32_t)arg;

    // Don't call esp_timer_get_time() in ISR - can cause watchdog issues
    // Debounce will be handled in the task instead
    gpio_isr_event_t evt = {
        .gpio_num = gpio_num,
        .level = gpio_get_level(gpio_num),
        .timestamp = 0  // Will be set in task
    };

    BaseType_t xHigherPriorityTaskWoken = pdFALSE;
    if (xQueueSendFromISR(s_gpio_evt_queue, &evt, &xHigherPriorityTaskWoken) != pdTRUE) {
        s_isr_queue_drops++;
    }

    if (xHigherPriorityTaskWoken) {
        portYIELD_FROM_ISR();
    }
}

static void dispatch_input_event(input_event_type_t type, int64_t now_us)
{
    if (type == INPUT_EVENT_NONE) {
        return;
    }

    s_last_activity_time = now_us;

    if (s_callback != NULL) {
        input_event_t input_evt = {
            .type = type,
            .timestamp = xTaskGetTickCount(),
        };
        s_callback(&input_evt);
    }
}

static void init_switch_state(active_low_switch_t *sw, int64_t now_us)
{
    int level = gpio_get_level(sw->gpio_num);
    sw->stable_level = level;
    sw->candidate_level = level;
    sw->candidate_since_us = now_us;
}

static void update_switch_state(active_low_switch_t *sw, int64_t now_us)
{
    int level = gpio_get_level(sw->gpio_num);

    if (level != sw->candidate_level) {
        sw->candidate_level = level;
        sw->candidate_since_us = now_us;
        return;
    }

    if (level == sw->stable_level || (now_us - sw->candidate_since_us) < SWITCH_DEBOUNCE_US) {
        return;
    }

    sw->stable_level = level;

    if (sw->tracks_force_restart) {
        s_btn_press_time = (level == 0) ? now_us : 0;
    }

    ESP_LOGD(TAG, "%s %s", sw->name, level == 0 ? "pressed" : "released");
    dispatch_input_event(level == 0 ? sw->press_event : sw->release_event, now_us);
}

static void update_all_switches(int64_t now_us)
{
    update_switch_state(&s_button, now_us);
    update_switch_state(&s_enc1_sw, now_us);
    update_switch_state(&s_enc2_sw, now_us);
}

// Process encoder state change, return direction
// Only triggers at detent position (state 11 -> next state)
static input_event_type_t process_encoder(uint8_t new_clk, uint8_t new_dt,
                                          uint8_t *state, bool is_enc1)
{
    uint8_t new_state = (new_clk << 1) | new_dt;

    if (new_state == *state) {
        return INPUT_EVENT_NONE;
    }

    input_event_type_t result = INPUT_EVENT_NONE;

    // Trigger on leaving detent (state 11)
    if (*state == 0b11) {
        if (new_state == 0b10) {
            result = is_enc1 ? INPUT_EVENT_ENC1_CW : INPUT_EVENT_ENC2_CW;
        } else if (new_state == 0b01) {
            result = is_enc1 ? INPUT_EVENT_ENC1_CCW : INPUT_EVENT_ENC2_CCW;
        }
    }

    *state = new_state;
    return result;
}
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

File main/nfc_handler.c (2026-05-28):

/*
 * NFC Handler Module Implementation
 * Wraps abobija/rc522 SPI driver behind a single-callback API.
 */

#include <stdio.h>
#include <string.h>
#include <stdbool.h>
#include "nfc_handler.h"
#include "esp_log.h"
#include "esp_timer.h"
#include "freertos/FreeRTOS.h"
#include "freertos/task.h"
#include "rc522.h"
#include "driver/rc522_spi.h"
#include "rc522_picc.h"
#include "picc/rc522_nxp.h"

static const char *TAG = "NFC";

// Suppress duplicate detections of the same UID within this window.
// RC522's heartbeat check can flicker when the card sits at the edge of the
// RF field, which would otherwise type the same string multiple times.
#define NFC_DEDUP_WINDOW_US (1500 * 1000)

// RC522 modules can miss the first reset/read test while the tablet OTG power
// rail and the module oscillator settle. Keep retrying instead of permanently
// disabling NFC after one boot-time failure.
#define NFC_START_RETRY_MS 5000

// Pin map: see CLAUDE.md "GPIO Pin Assignments" for net names + PCB position.
// IRQ (GPIO 5) is wired but not used here — polling mode handles edge detection
// inside the rc522 driver.
#define NFC_SPI_HOST    SPI2_HOST
#define NFC_GPIO_RST    4
#define NFC_GPIO_MISO   6
#define NFC_GPIO_MOSI   7
#define NFC_GPIO_SCLK   15
#define NFC_GPIO_SDA    16

static rc522_spi_config_t s_driver_config = {
    .host_id = NFC_SPI_HOST,
    .bus_config = &(spi_bus_config_t){
        .miso_io_num = NFC_GPIO_MISO,
        .mosi_io_num = NFC_GPIO_MOSI,
        .sclk_io_num = NFC_GPIO_SCLK,
    },
    .dev_config = {
        .spics_io_num = NFC_GPIO_SDA,
        // 1 MHz — conservative for flying-wire prototype to survive RF-transmit
        // noise. Library default is 5 MHz; bump after the carrier PCB lands.
        .clock_speed_hz = 1000000,
    },
    .rst_io_num = NFC_GPIO_RST,
};

static rc522_driver_handle_t s_driver = NULL;
static rc522_handle_t s_scanner = NULL;
static nfc_tag_callback_t s_callback = NULL;
static TaskHandle_t s_start_retry_task = NULL;
static volatile bool s_started = false;

// Last fired UID + timestamp, for de-duplication.
static char s_last_uid[RC522_PICC_UID_SIZE_MAX * 2 + 1] = {0};
static int64_t s_last_uid_time_us = 0;

// Parse a single NDEF Text Record out of NTAG user-memory bytes (TLV-wrapped).
// We only support the minimum subset that matches what `NFC Tools` and similar
// writer apps produce: short-record, well-known TNF, type 'T', UTF-8.
// Returns true and writes a NUL-terminated UTF-8 payload to out_text on success.
static bool parse_ndef_text(const uint8_t *buf, size_t buf_len,
                            char *out_text, size_t max_text_len)
{
    size_t i = 0;

    while (i < buf_len) {
        uint8_t tlv_tag = buf[i++];
        if (tlv_tag == 0x00) {
            continue;  // NULL TLV padding
        }
        if (tlv_tag == 0xFE) {
            return false;  // Terminator TLV — no NDEF found before this
        }
        if (i >= buf_len) {
            return false;
        }

        // TLV length: 1 byte unless first byte is 0xFF, then it's 3 bytes (0xFF + uint16 BE).
        size_t tlv_len;
        if (buf[i] == 0xFF) {
            if (i + 3 > buf_len) return false;
            tlv_len = (buf[i + 1] << 8) | buf[i + 2];
            i += 3;
        } else {
            tlv_len = buf[i];
            i += 1;
        }

        if (tlv_tag != 0x03) {
            // Lock-control / Memory-control TLVs etc — skip past their payload.
            i += tlv_len;
            continue;
        }

        // Found NDEF Message TLV. Parse its first record.
        if (i + tlv_len > buf_len) return false;
        size_t msg_end = i + tlv_len;

        if (i >= msg_end) return false;
        uint8_t hdr = buf[i++];
        bool sr = (hdr & 0x10) != 0;          // Short Record flag
        bool il = (hdr & 0x08) != 0;          // ID Length present
        uint8_t tnf = hdr & 0x07;
        if (tnf != 0x01) return false;        // Only Well-known type supported

        if (i >= msg_end) return false;
        uint8_t type_len = buf[i++];

        size_t payload_len;
        if (sr) {
            if (i >= msg_end) return false;
            payload_len = buf[i++];
        } else {
            if (i + 4 > msg_end) return false;
            payload_len = ((size_t)buf[i] << 24) | ((size_t)buf[i + 1] << 16)
                        | ((size_t)buf[i + 2] << 8) | buf[i + 3];
            i += 4;
        }

        size_t id_len = 0;
        if (il) {
            if (i >= msg_end) return false;
            id_len = buf[i++];
        }

        if (type_len != 1 || i >= msg_end) return false;
        if (buf[i++] != 'T') return false;    // Not a Text record

        i += id_len;  // skip optional ID

        if (i + payload_len > msg_end || payload_len < 1) return false;

        // Text payload: [status][lang_code][text]
        // status bit 7 = UTF-16 if set, bits 0..5 = lang_code length.
        uint8_t status = buf[i];
        if (status & 0x80) return false;       // UTF-16 not supported
        size_t lang_len = status & 0x3F;
        if (1 + lang_len > payload_len) return false;

        size_t text_off = i + 1 + lang_len;
        size_t text_len = payload_len - 1 - lang_len;
        if (text_len > max_text_len) text_len = max_text_len;

        memcpy(out_text, &buf[text_off], text_len);
        out_text[text_len] = '\0';
        return text_len > 0;
    }

    return false;
}

// Read enough NTAG user pages to (usually) cover an NDEF Text payload of
// length up to NFC_PAYLOAD_MAX_LEN, then parse. Returns true on success.
static bool try_read_ndef_text(rc522_picc_t *picc, char *out_text, size_t max_text_len)
{
    // 12 pages = 48 bytes — fits an NDEF Text record with up to ~38 chars
    // after TLV + header overhead. Three sequential 16-byte reads from page 4.
    enum { NDEF_BUF_LEN = 48 };
    uint8_t buf[NDEF_BUF_LEN];

    for (size_t off = 0; off < NDEF_BUF_LEN; off += RC522_NXP_READ_SIZE) {
        uint8_t page_addr = 4 + (uint8_t)(off / RC522_NXP_PAGE_SIZE);
        esp_err_t ret = rc522_nxp_read(s_scanner, picc, page_addr, &buf[off]);
        if (ret != ESP_OK) {
            ESP_LOGD(TAG, "NDEF read failed at page %u: %s", page_addr, esp_err_to_name(ret));
            return false;
        }
    }

    return parse_ndef_text(buf, NDEF_BUF_LEN, out_text, max_text_len);
}
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

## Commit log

2026-04-01 docs: V4 kickoff — update README/CLAUDE.md, add TODO, link project docs
2026-04-01 refactor: flatten USB HID firmware to project root, remove BLE firmware
    - tusb_hid/ → project root (CMakeLists.txt, main/, sdkconfig.defaults)
    - firmware/ (BLE HID, V1/V2) deleted — see git history
    - .gitignore: add Snipaste_*, apk/, models/, IDE config
2026-04-01 docs: sync 04-01 meeting outcomes — cost, delivery, NFC count, button spec
2026-04-16 docs: 项目文档合并 — 从 ~/hao 迁入 BOM、PCB spec、R1-R3 归档
    移除指向 ~/codex 的断链 symlink，将项目文档直接纳入 repo。
    更新 CLAUDE.md：补充项目暂停状态、客户信息、关联归档仓库。
2026-04-16 fix: astro-pager 描述修正 — 超脑AI孵化器黑客松项目，非明德实验学校
2026-04-30 docs: v4 — sync Arthur prototype restart scope
2026-04-30 docs: pcb — compare integrated USB charge options
2026-04-30 docs: pcb — require wired HID path
2026-04-30 docs: pcb — archive Tab A9 OTG charge research
2026-04-30 docs: pcb — clarify SS34 validation variants
2026-04-30 docs: pcb — record OTG split-cable integration path
2026-05-10 fix(firmware): NFC startup non-fatal — survive missing/unresponsive RC522
    ESP_ERROR_CHECK(nfc_handler_start()) was crashing the chip into a reboot
    loop whenever the RC522 was disconnected, masquerading as "input handler
    unstable" on bare DevKitC test rigs. Demote nfc_handler_init/start to a
    warning + continue path so knobs/button/HID stay alive without NFC.
    [tusb_hid_example_main.c]
2026-05-15 docs(hardware): OTG adapter spec + DevKitC N16R8 reference assets
    Internal OTG split-cable subboard (YK16-09E V1, etched 240919): how the
    Tab A9 ends up simultaneously a USB Data Host (sinking HID from the
    ESP32) and a Power Sink (charging from external supply). Also adds the
    DevKitC N16R8 product image for pin-map reference.
    README docs index links to the new hardware doc alongside usb.md/nfc.md.
2026-05-22 feat(v4): PCB r1.0 实焊验证完成 + 文档 SSOT 重构
    PCB r1.0 (JLCEDA Pro 手绘 P1.epro2) 已打板 + 焊接 + 双板并排验证通过。
    EC11-R 因 J4 引脚顺序在原理图里画成跟 J3 镜像，物理 EC11 端子线序错位 ——
    固件层 walkaround：input_handler.c 重新指派 GPIO_ENC2_A/B/SW 角色，并 swap
    A↔B 让两个旋钮"向内拨"方向一致。硬件不返工。
    文档执行项目级 SSOT 重构：
    - CLAUDE.md "GPIO Pin Assignments" 是 GPIO ↔ net ↔ J pin 的唯一来源
    - main/input_handler.c + main/nfc_handler.c 的 #define 是固件 GPIO 角色的
    唯一来源（编译器是 enforcer）
    - 其余 9 处文档原本各自维护 GPIO 数字 / J 编号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
    [CosmoradioV4Carrier.kicad_pcb]
2026-05-24 docs(v4): 结项整理 — PCB SSOT 归位 + 验证/交付/成本文档 + 文档同步
    把 V4 整理成"最终验证可交付版本"并为交接做准备。
    ## 本次进度
    - PCB SSOT 修正：验证版设计源是 JLCEDA 手绘 r1.0（导入 pcb/cosmoradio-v4-jlceda/，
    含 .epro2 + 原理图渲染 PNG）。删除仓库里从未打样的 KiCad Plan-v2 + 空壳 .eprj2
    （pcb_count=0、design 表全空，是误导项；可从 git 历史追溯）。
    - pcb/README.md 重写：以验证版为核心 + 嘉立创EDA专业版制造文件导出步骤清单。
    - 新增文档：
    - docs/project/CosmoRadio-V4-技术验证报告.md（交付核心，各子系统验证记录 + 已知限制 + r1.1）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
    [CosmoradioV4Carrier.csv, CosmoradioV4Carrier.kicad_pcb, CosmoradioV4Carrier.kicad_sch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]
2026-05-28 fix(firmware): 输入释放与 NFC 启动可靠性
    - 对 Action Button / EC11 SW 增加 active-low 状态机和 10ms GPIO 电平复核，释放沿丢失时仍会补发 key-up。
    - HID report busy 时等待并由后台 retry task 补发当前按键状态，避免 release report 被 endpoint 忙丢弃。
    - RC522 start 失败后后台 5s 重试，避免开机瞬时失败永久禁用 NFC。
    [input_handler.c, nfc_handler.c, tusb_hid_example_main.c]
2026-05-28 docs(v4): 归档交付包 — 清理 project 文档副本
    - 将 project/ 明确为本地项目管理和飞书交付镜像，不再保留 docs/project 的重复追踪副本。
    - 同步 README / CLAUDE / TODO / 硬件文档链接到当前 project/v4/shared 资料包，并记录 2026-05-28 固件安全回归。
    - 归档 PCB r1.0 制造导出文件，并用 .gitattributes 标注 PDF/XLSX/ZIP/STEP/DXF 的 diff 属性。
    [CosmoRadio-V4-PCB-r1.0-BOM.xlsx, CosmoRadio-V4-PCB-r1.0-BoardOutline.dxf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]
2026-05-29 docs(firmware): 烧录端口指引 — UART(CH343)/OTG 口区分 + 复位陷阱
    本次烧录踩坑沉淀：cable 插到 native/OTG 口（VID 0x303A，跑 TinyUSB HID）时
    auto-reset 进不了下载模式，报 "No serial data received"。本板 UART 桥是
    WCH CH343（VID 0x1A86，非 CP2102N），macOS 下两个口都枚举成 usbmodem，
    必须靠 USB VID 区分而非端口名。另：serial-monitor skill 的 DTR/RTS 软复位
    在 CH343 这类外置桥上会把 IO0 拉低误进下载模式，干净重启已烧固件用
    `esptool run`。
    CLAUDE.md 新增「烧录端口」子节（VID 区分表 + CH343 说明 + esptool run）；
    README 构建与烧录段加交叉引用；AGENTS.md 为 CLAUD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
2026-06-01 docs(v4): 第四期结项 — 收款 ¥5,000 + 交付日期更正 + 发票归档
    第四期技术验证 + 单套原型已结项：技术验证 2026-05-22 完成，
    2026-05-31 客户收到成品交付，2026-06-01 开票收款 ¥5,000，累计 ¥31,000 全部结清。
    发票（电子普票 26952000002267233876）已归档至 project/v4/internal/项目发票/
    并上传飞书项目交付文件夹（project/ 为 gitignore，不入库）。
